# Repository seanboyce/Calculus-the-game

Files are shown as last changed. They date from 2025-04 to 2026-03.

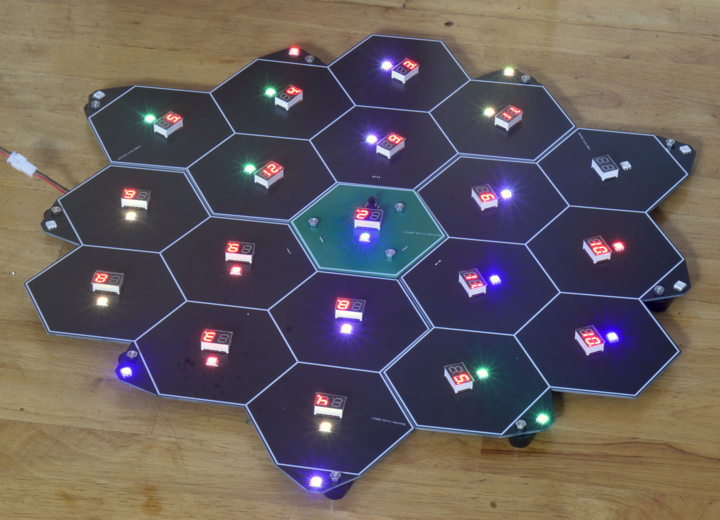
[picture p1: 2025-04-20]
calculus_full/fullboard_power.JPG

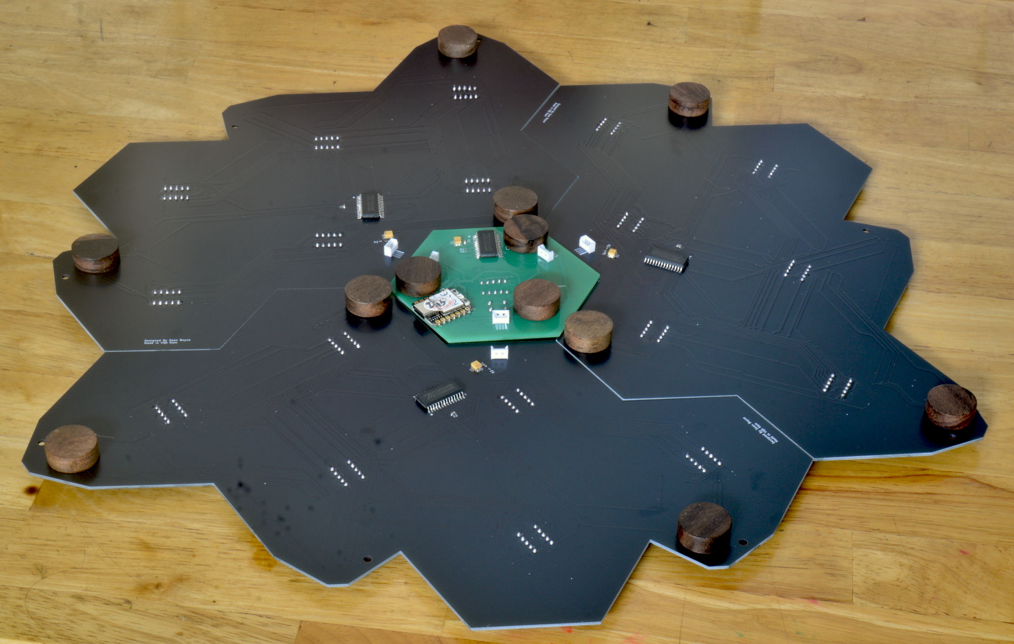
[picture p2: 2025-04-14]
calculus_full/verso.JPG

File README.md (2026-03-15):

# Introduction
An electronic strategy board game about mining an asteroid and barter. It is also fully compatible with Settlers of Catan. So if you already own that game, you can play it using this board if you wish (using the cards and pieces from the original). The holders of the Catan copyright also generously allow you to make one (1) handmade copy of their game for personal use. A practical thing to do is buy their game, and use the included pieces and cards (although please note the pieces will only physically fit the full-size version, see below). For more information on IP, please visit this link: https://www.catan.com/guidelines-dealing-intellectual-property-catan

Out of respect for their IP (and also for fun), my own game will be sci-fi themed and will not use or refer to their IP beyond this point. 

## Sci-Fi theme?
The name of the game is Calculus, in the sense of a "stone, or concretion of material". In this case, an asteroid in deep space! You are one of up to four corporations that are racing to exploit this valuable asteroid. The corporation that reaches a certain level of development (10 Infrastructure Points) first will own this tiny piece of the sky. This is the object of the game. Besides the four corporations, a mysterious hacker has made their home here, and is bound to interfere with your plans...

(for more information, read the short, bewildering manual)

# Status
The electronics and firmware are in a finished state. Game and reference cards exist and are usable, but the design is nothing special. The game manual is an A5 saddle-stitched booklet, available as a pre-imposed, print-ready document. If you want to help, please redesign my print materials. You are very likely better at this than I am.

There are two versions of this game, both complete:

1. The cheap version (about USD 15.00 to manufacture 1 unit in Asia) -- this version only has one PCB, although you will need 3 units to build the game. It is very cheap to manufacture, but a bit small and cramped to play. Call it a "travel version"! It is missing a little polish overall, and the firmware (while completely functional) is a little chaotic. Notably, trade ports are not electronic (I use magnetic discs), the landing zone (unproductive tile) is limited to being in the center of the board, and there's no MCU on the board itself -- it needs to be added externally and wired in to the inputs. You'll also need to hack in a button. Still, it's very cheap to make and perfectly cromulent.
2. The full-size version (about USD 37.50 to manufacture 1 unit in Asia) -- this one is *much larger* (more than double the size). It uses two PCBs: a large one (you will need 3), and a small one (you will need 1). The small PCB has space for an MCU, making the final board much more self-contained. The small board goes in the center and is also an active game tile -- the landing zone (unproductive tile) can be randomized like other tiles because of this. Trade ports are randomized and represented by RGB LEDs like resource tiles (or off for 3:1). There are also some cosmetic improvements like a proper button and nicer lines. I've also substantially cleaned up the firmware to control all those LEDs -- there are 388 (!) LEDs on the board when you count up all the RGB LEDs and two digit 8-segment displays. 

Other than noted above, both versions play the same. 

## Power
It's expected that you power the game via a USB battery bank. Like the kind you use to recharge phones. However, you can power it from any USB port or 5V source. Current consumption at 5v should be around 250mA for the cheap version, and a little higher for the full version (say 300mA).

Note that some power banks will automatically turn off if the power draw is too low. When pressing the 'next turn' button, the power draw can dip below this threshold, causing the game to turn off and lose it's state! To avoid this, some power banks have a 'low current mode' that disables this feature -- check your powerbank manual.

An alternative solution is to put a resistor across power and ground to increase the current draw. A 100 ohm resistor was sufficient in my case. This adds 50mA to the current consumption, but still keeps it low enough that my power bank will run the game for 30 hours or so per charge.

Building your own rechargeable power supply, or powering it from a phone charger instead of a battery are also reasonable solutions!

## CPU
The cheap version of the game can use more or less any RP2040 based board. The original Pi Pico works fine. The full version specifically requires the XIAO RP2040 -- it's smaller and I needed the space.

## Structural
The boards for the cheap version are intended to be attached above a small project box or similar. This serves the dual purpose of housing a microcontroller, and fixing the 3 PCBs firmly in place. The larger board has all those electronics integrated, and is meant to be bolted to something rigid. I use a circular bamboo serving tray, this leaves a hollow space under the board suitable for storing pieces, the power supply, and the manual.

You can also just add rubber feet to the PCB, the type that are used for furniture and attach on via M3 bolts. This will let you rest it on most flat sufaces. These should be at least 8mm high for proper clearance, I found 10mm more practical. The benefit of this approach is that you can 'stack' the 3 big PCBs, and store the game in a smaller box. On the other hand, it offers no strain relief on the cabling (which can get a bit tangled). I found that bolting it to a rigid surface was much more practical.

## Game Pieces
The cheap requires custom pieces -- hex spacers, bolts, and nuts colored with a permanent marker work fine. The full size board can be played with pieces from a Catan set, or you can make your own.

I like the weight of metal game pieces -- so I dyed 25mm brass hex spacers as the 'tunnels', dyed M6 nuts as the 'mines', and add a ~13mm dyed M6 bolt to them to upgrade them to 'drills'.

To dye these metal pieces, colored permanent marker worked really well.

# Firmware
Besides the assembled PCBs, you will need to load firmware to the main microcontroller (an RP2040). This is pretty easy and can be done over USB. The firmware is heavily commented -- this is so you can make 'house' modifications to the game mechanics, to change the rules if you want. You could even design a completely new game!

# Notes on Assembly
Assembling the PCBs will require that you are comfortable with surface-mount soldering. It's not nearly as hard as it looks. You'll need solder paste and a hot air rework station though. If you don't have these, check if there's a hackerspace near you. They probably will! The default designs use 0402 (1005 metric) components. If you want something easier to solder, look for the 0603 version of the kicad and production files in the fullsize board directory. 

# Having Trouble? Something Confusing?
Raise an issue here on Github. I check in from time to time and will likely respond.

# Image of Completed Board (full version)
Photo of the completed full version of the game

# Image of Completed Board (cheap version)
Photo of the completed small version of the game

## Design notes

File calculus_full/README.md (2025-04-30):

## Resistor sizes

I've supplied two versions of the kicad and production files. The default version uses 0402 (1005 metric) components. Many people would find these hard to hand solder -- they are about the size of two grains of salt. If you want something easier to solder, check out the 0603 version -- there's a zip file with the KiCAD and production files. Strictly speaking, it's not tested (I made the 0402 version). However, the only thing I did is change the resistor footprints, so it should be fine. 

## Note the production files are in metric units

If you need to switch it to some other system, you'll need to open the KiCAD files and generate your own production files (it's very easy)

Also note these boards have a little note in silkscreen on the back with my name and where they were designed. It's meant to be a kind note that I cared to design these for you, and I hope you enjoy them.

You may remove it if you wish. Just open up the PCB in KiCAD, select the text, and press delete. Then re-export the production files.

## KiCAD files

There are some custom footprints I think? Not sure how that gets handled. Let me know if anything outright breaks.

The routing is still pretty YOLO in this version (although less bad than the cheap version), feel free to clean it up. I tried to mostly keep traces off the top of the board so it looks clean.

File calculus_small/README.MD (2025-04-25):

# Pieces
For this game size, brass hex spacers, bolts, and nuts work really well.

- Hex spacers are 'tunnels'
- Nuts are 'mines'
- Nuts with a bolt slightly screwed in are 'drills'

If you color them with permanent marker, they look quite nice.

# Routing
Yeah, the routing on this board is very YOLO. Feel free to make improvements. I have only a few hours of free time per week so optimized for getting the thing done.

# Notes
The production files are in metric units.

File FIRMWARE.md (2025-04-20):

## Make sure to use the right version of the firmware for your game.

Unlike some of my other projects, this is purely written in micropython rather than AVR assembly. I wanted it to be more accessible to beginners, and the extra power use by the RP2040 is pretty irrelevant in the context of all the LEDs.

The firmware uses the tm1640 driver from here: https://github.com/mcauser/micropython-tm1640. The licence for that code is different from the rest of this project, and defined in that file.

To learn how the firmware works, your best bet is to read the source code in main.py for the full version of the game. It's heavily commented.

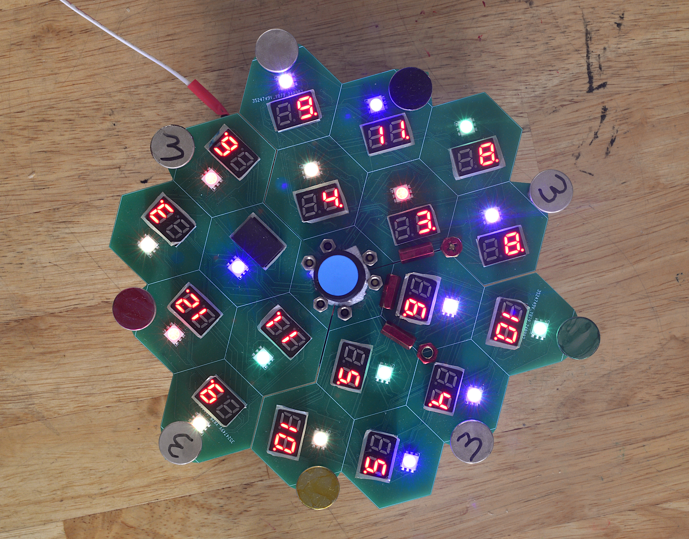
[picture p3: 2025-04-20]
calculus_small/calculus_small.JPG

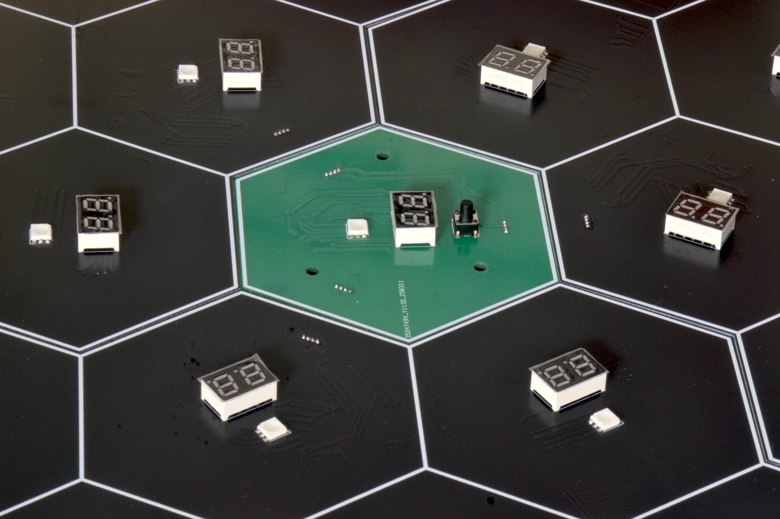
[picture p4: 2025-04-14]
calculus_full/unpowered_close.JPG

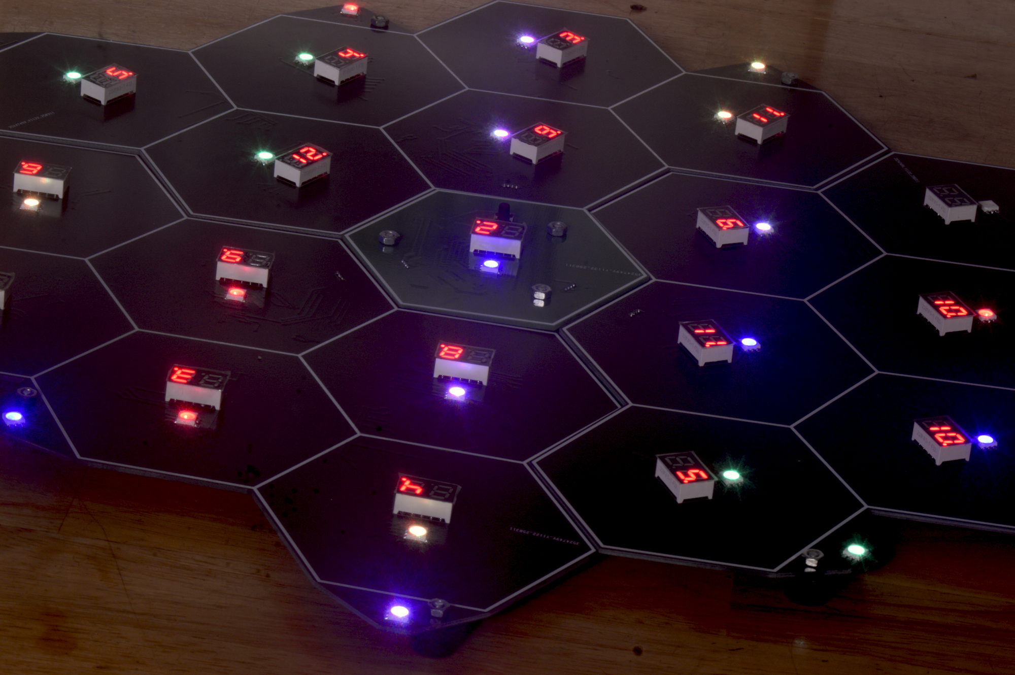
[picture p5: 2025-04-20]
calculus_full/closeup_power.JPG

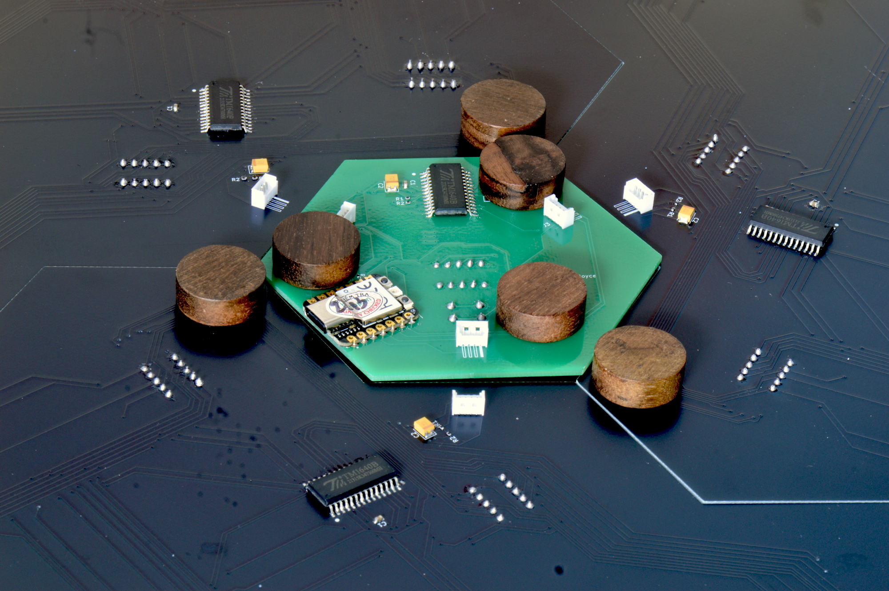
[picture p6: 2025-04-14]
calculus_full/verso_close.JPG

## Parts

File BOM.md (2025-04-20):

All parts surface-mount unless otherwise noted. Let me know if I've missed something. Black PCBs look pretty cool with this design.

## for 3 Main segments
- 3x TM1640 LED drive control IC
- 18x two-digit LED display, common ground (I used 2821AS, these are through-hole parts)
- 27x 5050 RGB LED
- 3x 1.25mm ZH female connector (these are through-hole parts)
- 3x 1411 Tantalum capacitor 100uf 6.3V
- 3x 0603 0.1uF ceramic capacitor 50V
- 6x 0402 10k ohm resistor
- 3x PBC subunit

## For center tile
- 1x TM1640 LED drive control IC
- 3x 0402 10k ohm resistor
- 1x 1411 Tantalum capacitor 100uf 6.3V
- 1x 0603 0.1uF ceramic capacitor 50V
- 1x 5050 RGB LED
- 1x generic pushbutton. Check the board for dimensions, it's one of the super common types (this is a through-hole part)
- 1x two-digit LED display, common ground (I used 2821AS, these are through-hole parts)
- 1x XIAO RP2040 module (we're using it as a surface mount part!)
- 3x 1.25mm ZH female connector (these are through-hole parts)

## General
- 3x 1.25mm male-male connector (cable). Mind the pinout, some cables reverse pin order.
- 1x USB external battery for phone (to power the game)
- 1x male USB cable (for power). Probably you want one end USB, then solder the power lines directly to the center tile. I've left yo usome pads for this, but anywhere 5V/GND goes is fine.
- 15x 3mm wide bolt+nut (length depends on the rubber feet you choose)
- 15x rubber foot. Minimum length 8mm. Recommend 10mm. You can also bolt the boards to a surface instead of using feet.

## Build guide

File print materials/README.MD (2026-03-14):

# Print Materials
These are the (optional) print materials for Calculus. Each indicates how many copies of the file you'll need to print to have enough pieces.

## Manual

The manual is a bit of a special case. There's a .odt file if you want to edit it, but I've also made an attempt to lay it out into A5 pages. This lets you print it as a saddle-stiched A5 booklet. The "imposed" version is ready-to-print (duplex on long edge). The other version assumes you'll handle the page imposing yourself.

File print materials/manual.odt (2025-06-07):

Prelude

The year is unknown.

Long ago, the Earth could no longer sustain our hunger. We fled like locusts to the stars. But they were strange, and far. They did not want us, and we could not reach them.

There were nearer worlds. Dusty and without breathable atmospheres, space was safer. There was always energy available from sunlight – as long as you avoided gravity wells, the only resources of consequence were mass and time.

The asteroid belt had plenty of metals, and very little gravity. We learned long ago that economic competition was the most efficient way to deplete resources. We parceled out each to four corporations – immortal and amoral -- who would compete to devour them fastest, and thereby claim ownership.

You direct one of these. It is vast, and cold, and empty. A space devoid of stars.

Calculus: The Game

Calculus is a game of resource management and barter for 3-4 players. The word ‘calculus’ means “a stone, or concretion of material”, in this case an asteroid in deep space. The synonymity with the maths subject is not accidental either!

Before you begin, you should make sure you possess the following components:

1x game board

1x USB power bank

95x resource cards – 19 each of Iron, Titanium, Gold, Uranium and Ice

1x hacker token

4x game reference cards

16x drill pieces (four of each color)

20x mine pieces (five of each color)

25x black market cards namely:

14x Cyborg Mercenary

2x Alien Artifact

2x Space Pirates

2x Tunnel Borer

1x Fission Reactor

1x Research Lab

1x Silicon Foundry

1x Biodome

1x Data Center

Starting the Game

No dice are required to play Calculus, it is handled electronically. The board will set itself up automatically upon receiving power. Do not disconnect power while playing the game – it will not save your game state.

Objective

The objective of the game is to be the first player to accumulate 10 Infrastructure Points (IP). If during your turn, you have 10 IP, you win the game. You may only win the game on your turn!

There are 5 sources of IP:

Mines | 1 IP
Drills | 2 IP
Longest Tunnel (at least 5) | 2 IP
Biggest Army (at least 3) | 2 IP
Black Market cards, namely: Fission Reactor Silicon Foundry Research Lab Biodome Data Center | 1 IP each

Hint: It is generally practical to use a game piece to track which player currently has the largest army and longest tunnel. If you don’t 3D print one, you could design a card, or just use two different coins.

Building

Building facilities, armies, and tunnels costs resources. These are Iron (red), Titanium (blue), Gold (gold), Uranium (green), and Ice (white). There is a summary of what each costs on the game reference cards and below:

Mines | 1 Iron, 1 Uranium, 1 Gold, 1 Ice
Drills | 2 Gold, 3 Titanium
Tunnel | 1 Iron, 1 Uranium
Black Market cards | 1 Gold, 1 Ice, 1 Titanium

Mines and drills (facilities) can only be built on corners of the hex tiles, and must be connected to a tunnel. Facilities must be a minimum of two edges apart (e.g. not on adjacent corners of a hex tile).

Drills must always replace existing mines when built. Think of them as an upgrade.

Tunnels exist along the edges of the hex tiles, cannot intersect or overlap each other, and must be connected to your existing tunnel network. If your tunnel network is interrupted by another player’s facility, the tunnels past that facility no longer count as part of your network.

Gaining Resources

When any player starts their turn by pressing the button in the middle of the board, the game will electronically roll two dice, and one of two things will happen:

1. The hex tiles that produce resources will flash. Each player with a facility touching those tiles will gain one resource of the type indicated by the colored LED. If you have a mine, you gain one resource card of that type. If you have a drill, you get two. If you have more than one facility touching the flashing tiles, you gain resources from each.

2. All tiles flash! You have been contacted by the Hacker. You may move them to any hex tile – that tile no longer produces resources while the Hacker remains. You may also take up to 1 resource card at random from one player, if they have a facility touching that tile. Finally, any player with more than 7 resource cards in their hand must choose and discard half (rounded down).

You should keep your resource cards hidden from other players.

Probability of Different Tiles Producing Resources

The numerical LEDs on each tile tell you what number needs to be rolled (on two dice) for that hex tile to produce resources. Numbers closer to 7 are more likely, like with actual dice. In other words, 8 and 6 are the most productive hex tiles. 2 and 12 are the least productive.

Each possible roll has two tiles except 2 and 12 which occur once (these rarely produce resources), and 7 which summons the Hacker instead of producing resources.

You may notice that one tile has no number. This is the “Landing Zone”. The Landing Zone produces no resources, and the Hacker starts the game there.

Just in case it’s not clear, this is the resource that each tile produces, according to the LED color:

Red tiles produce Iron

Blue tiles produce Titanium

Yellow tiles produce Gold

Green tiles produce Uranium

Trading Resources

You may trade resource cards with any player, but all trades must involve the player whose turn it currently is.

You may also trade resources with the market during your turn. The market hungers and will not offer you a great rate – 4 of any one type of resource for one resource of your choice. There are some things you can do to get a better rate:

1. If you own a facility touching one of the unlit LEDs on the outside of the board (not on a hex tile), you may trade three resources of the same type for one resource of your choice. These are the general trade ports.

2. If you own a facility touching one of the lit LEDs on the outside of the board (not on a hex tile), these are the specialized trade ports. You may trade two resources of the same color as the LED for one resource of any type.

In both of these cases, the facility must be build on a hex corner directly connected to the trade port, and not on some further part of the hex tile.

Generosity is a Crime

Your shareholders do not tolerate generosity, it is punishable by death. You may not give resource cards to another player for free. This includes combining a series of trades that results in one player receiving free resources from another at no net cost.

For example, you cannot trade another player two Iron for three Iron. Neither can you trade an Iron for a Uranium and Ice, then immediately trade one Ice for one Iron – one player netting a free Uranium at no cost. There must always be a cost, the market demands it.

Turn Actions

Calculus is a turn-based game. Each turn has two phases: Resource Extraction and Action.

Resource Extraction Phase

Players start their turn by pressing the button in the center of the board – this rolls the electronic dice, starting the Resource Extraction phase.

The game will automatically determine which tiles produce resources and flash the numbers on those tiles. Players take one resource of that tile’s type for every mine touching it, and two for every drill. If all tiles blink, the Hacker has contacted you, in this case no resources are produced.

Any tile with the Hacker present produces no resources. The landing zone also produces no resources. To indicate this, it is convenient to use a small piece of black plastic to cover the numeric LED display.

If there are not enough resource cards left for a player to receive them, no player receives those resources on this roll. For example if two players need to receive Titanium, but there’s only one card left, neither player receives any Titanium. If only one player needed to receive two Titanium, then they could draw the remaining card.

Spent and discarded resources are returned to the pile.

Action Phase

If it is your turn, you may now trade with any other player (or the market). You may buy Black Market cards, build tunnels, mines, and drills. You may do these as many times as you want, provided you have the resources. (Some players like to put a time limit on turns, but that’s up to you.)

You may also play one Black Market card, unless you drew it this turn. One exception: you may play any number of the following cards if they bring you to 10 Infrastructure Points:

Fission Reactor

Silicon Foundry

Research Lab

Biodome

Data Center

Generally it is to your advantage to conceal these cards until that happens.

If at any point during your turn, you have 10 Infrastructure Points, you win the game! If you reach 10 Infrastructure Points during another player’s turn, you do not immediately win the game. You must wait until your turn begins.

Black Market Cards

During your turn, you may buy Black Market cards with one gold, one ice, and one titanium. You should keep these cards hidden from the other players. Once deployed, Black Market cards do not return to the pile. If they run out, no more may be purchased.

Black Market cards cannot be traded, cannot be stolen by the Hacker (professional courtesy), and cannot be deployed the turn they are drawn.

The only exception are the 5 cards that give you Infrastructure Points:

Fission Reactor

Silicon Foundry

Research Lab

Biodome

Data Center

These do not need to be deployed at all. They are worth 1 Infrastructure Point each. If they would bring you to 10 Infrastructure Points during your turn, you reveal them and immediately win the game.

The other Black Market cards work as follows:

Cyborg Mercenary: Move the Hacker to a tile of your choice. This means you may steal one resource card from one player with a facility touching that tile. The Cyborg Mercenary counts towards “Largest Army”. If you have the most mercenaries (and at least 3), that’s worth two Infrastructure Points.

Moving the Hacker this way does not require that players discard resource cards if they have more than 7.

Alien Artifact: Not much is known about this thing, but it’s certainly valuable. You may deploy this card to gain any two resources (they don’t have to be the same type)

Tunnel Borer: This boring machine lets you immediately build up to two tunnels at no resource cost.

Space Pirates: Driven mad by silence and time, they will steal all resources of one type of your choice, from all players, and give them to you. For example if you name “Iron”, all players must hand you all of their iron.

The Hacker

Bound by the mandates of their unknowable gods, the Hacker will contact you to offer their services every time you roll a 7 (all the numerical displays will blink to indicate this).

First, any player with more than 7 resource cards must choose and discard half of them (rounded down). The Hacker is a heretic that hates greedy corporations.

You may then move the Hacker to a tile of your choice. That tile produces no resources until the Hacker is moved again.

The Hacker, in their generosity (a capital offense) will also let you steal one resource card at random from one player who has a facility touching the tile you just moved the Hacker to. You may only select one player to take a card from this way.

The Hacker begins the game in the Landing Zone – the tile that has no number on it.

Determining the Longest Tunnel

When determining the longest tunnel, do not count branches. Only count the longest route that you can travel without doubling back.

If someone places a facility along your tunnel, that creates a blockade! You may not pass a blockade when counting the longest tunnel.

Setting up Your First Game

Now that you know the rules, lets set up your first game.

First, choose a player and turn order any way you wish. One practical method is to press the button in the center of the board and see who gets the highest number, then proceed to the left. Resolve any ties by trying again.

Next, players place one mine each according to their turn order. Then they place one tunnel on an edge connected to that mine. Facilities must remain at least two edges apart.

Then, in reverse turn order, players place a second mine anywhere on the board (but again, at least two edges away from other facilities). Next, they place a tunnel connected to this second mine.

This means that the last player to place their first mine, is the first to place their second mine.

Finally, each player takes one resource card of each type connected to their second mine, as indicated by the colored lights on the tiles. These are your starting resources (up to 3 cards). The landing zone produces no resources.

Now, the first player’s turn begins.

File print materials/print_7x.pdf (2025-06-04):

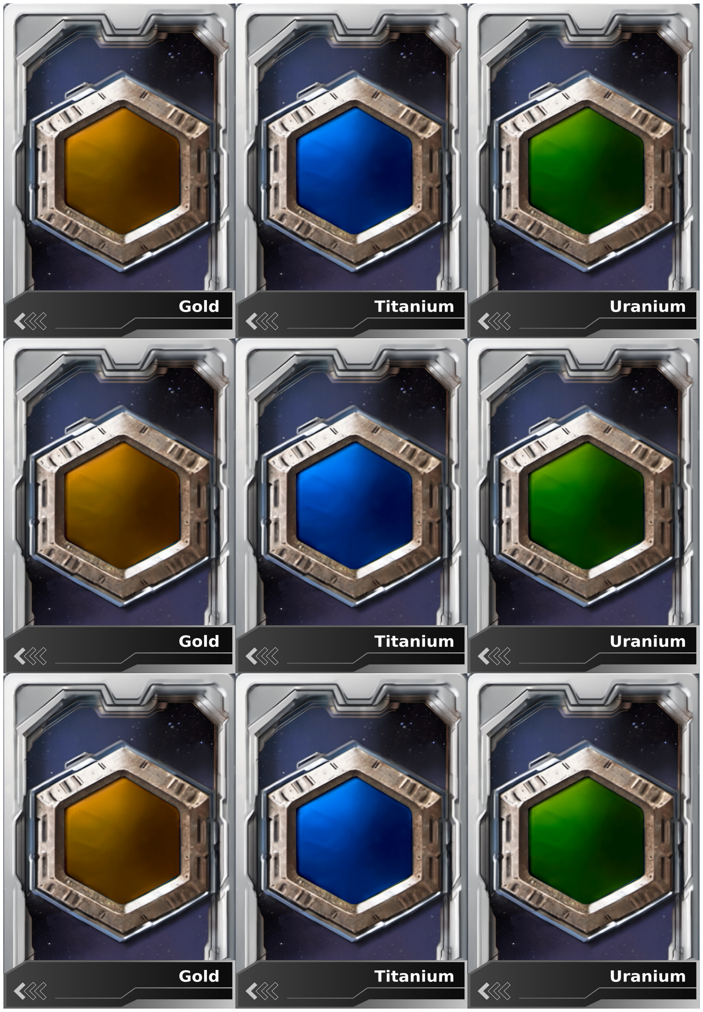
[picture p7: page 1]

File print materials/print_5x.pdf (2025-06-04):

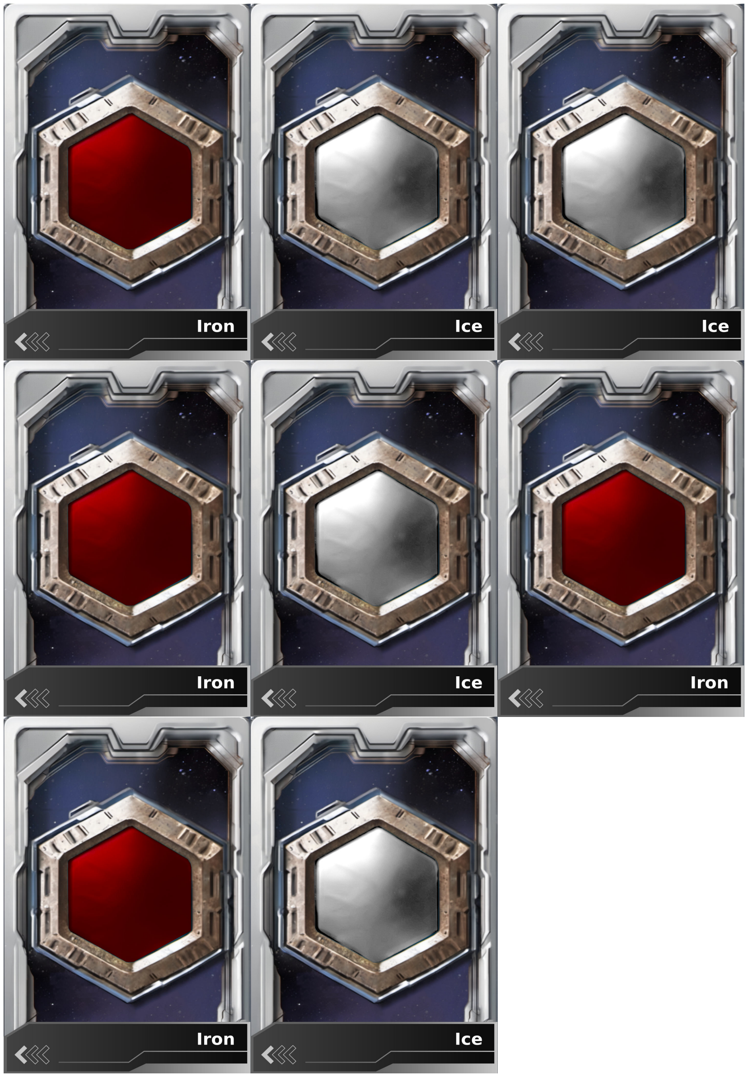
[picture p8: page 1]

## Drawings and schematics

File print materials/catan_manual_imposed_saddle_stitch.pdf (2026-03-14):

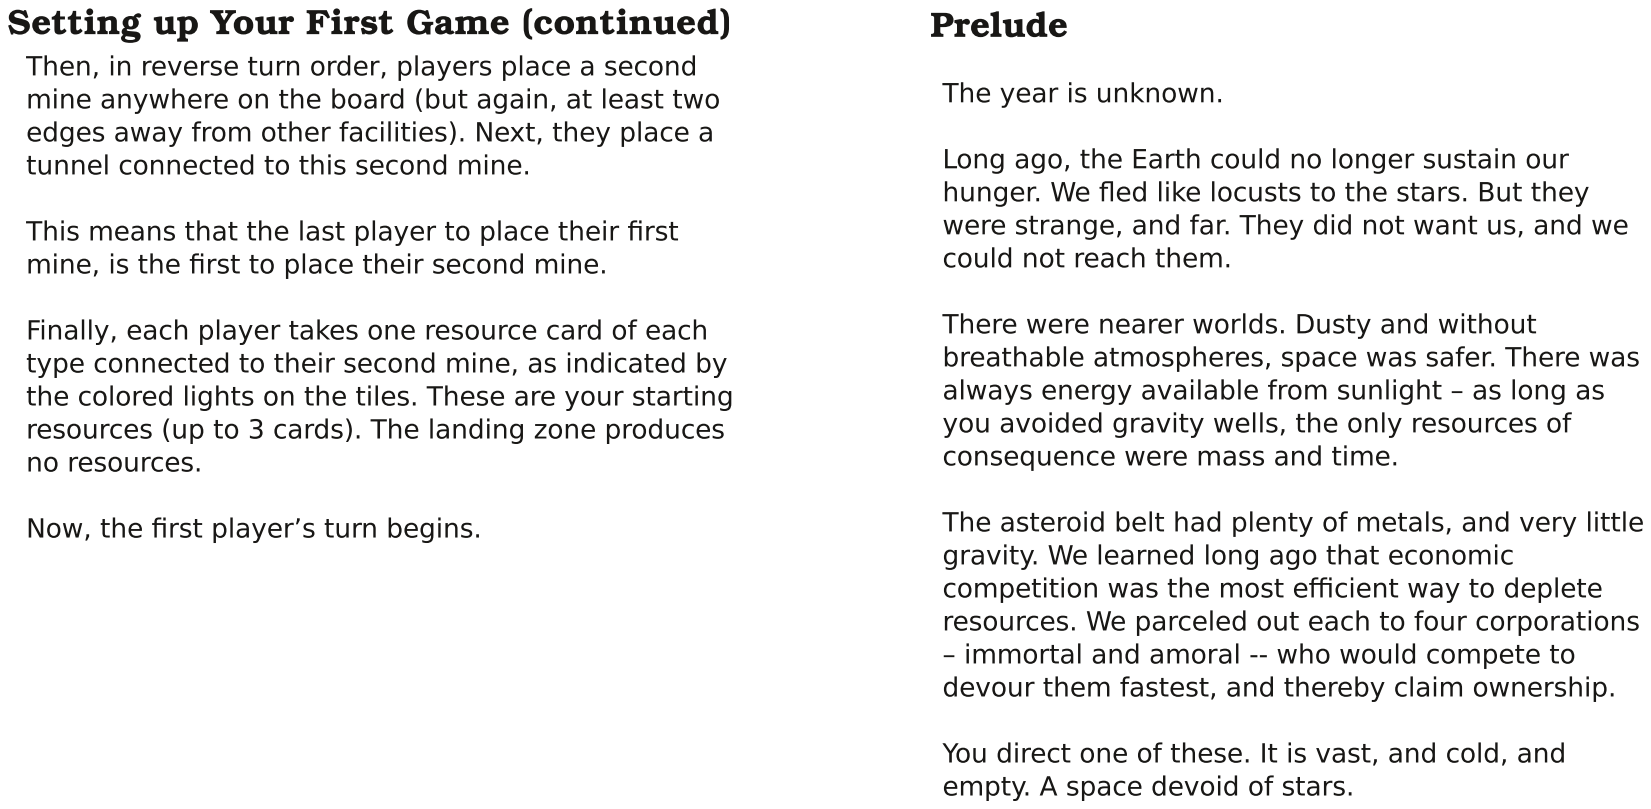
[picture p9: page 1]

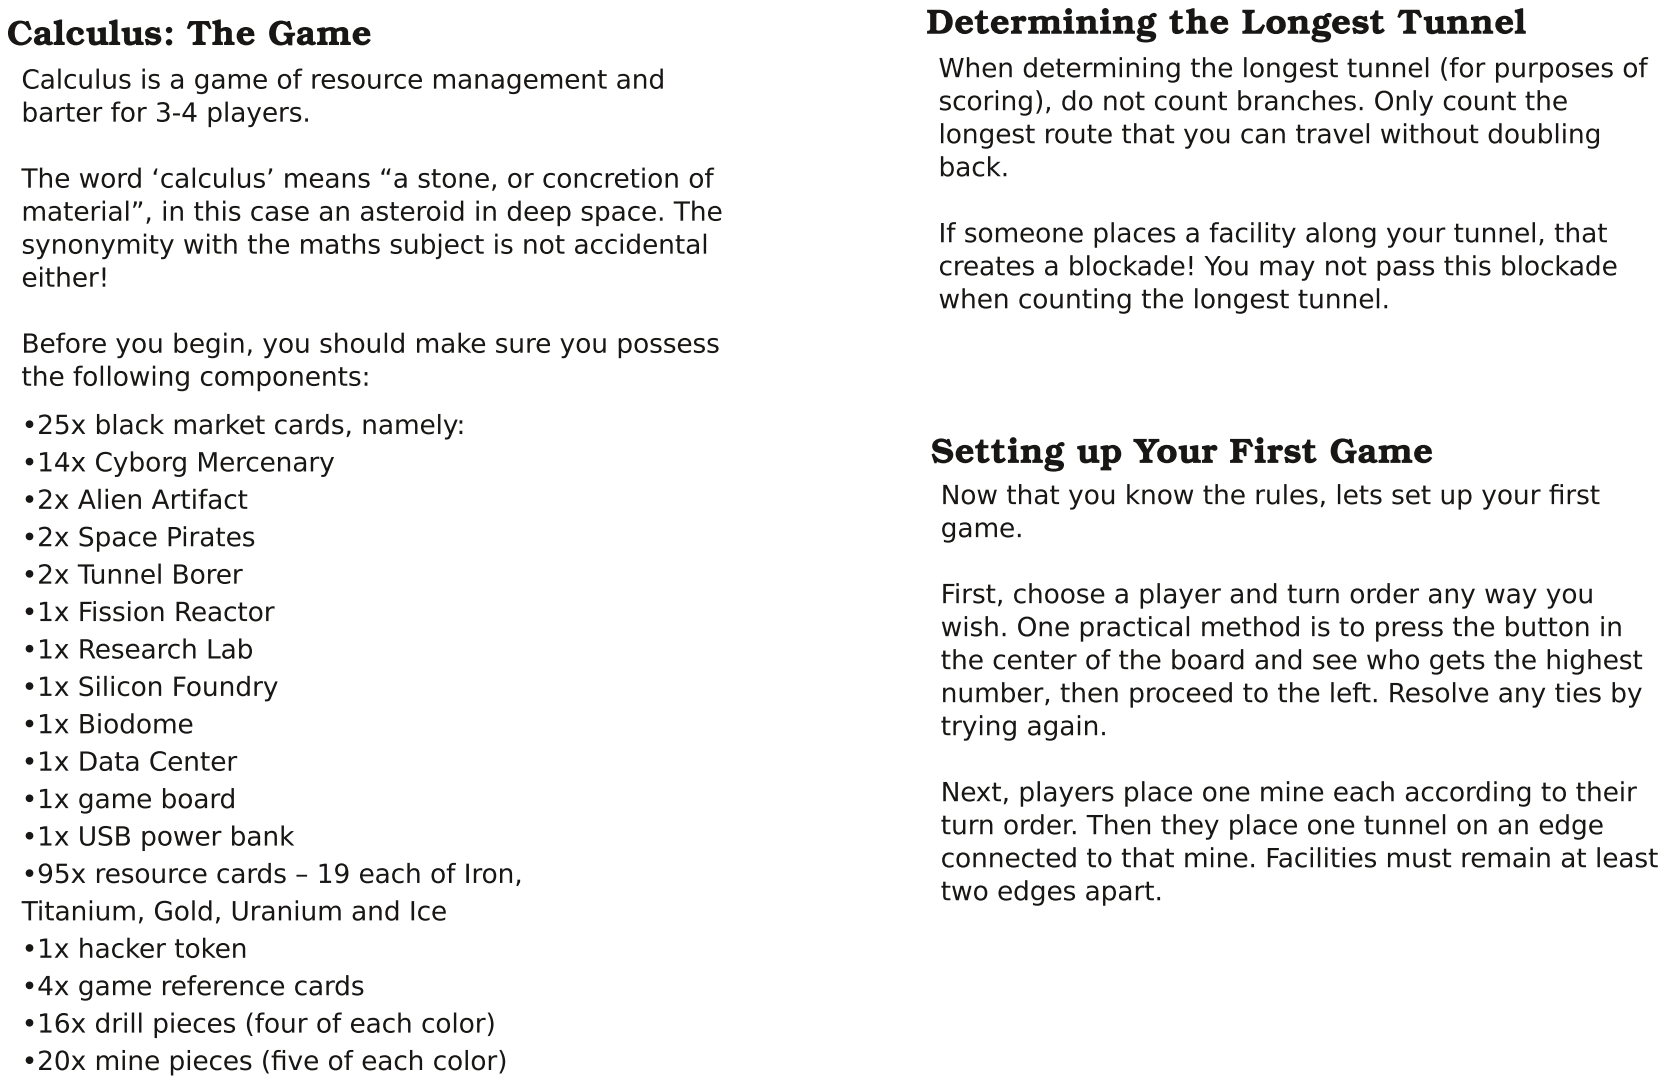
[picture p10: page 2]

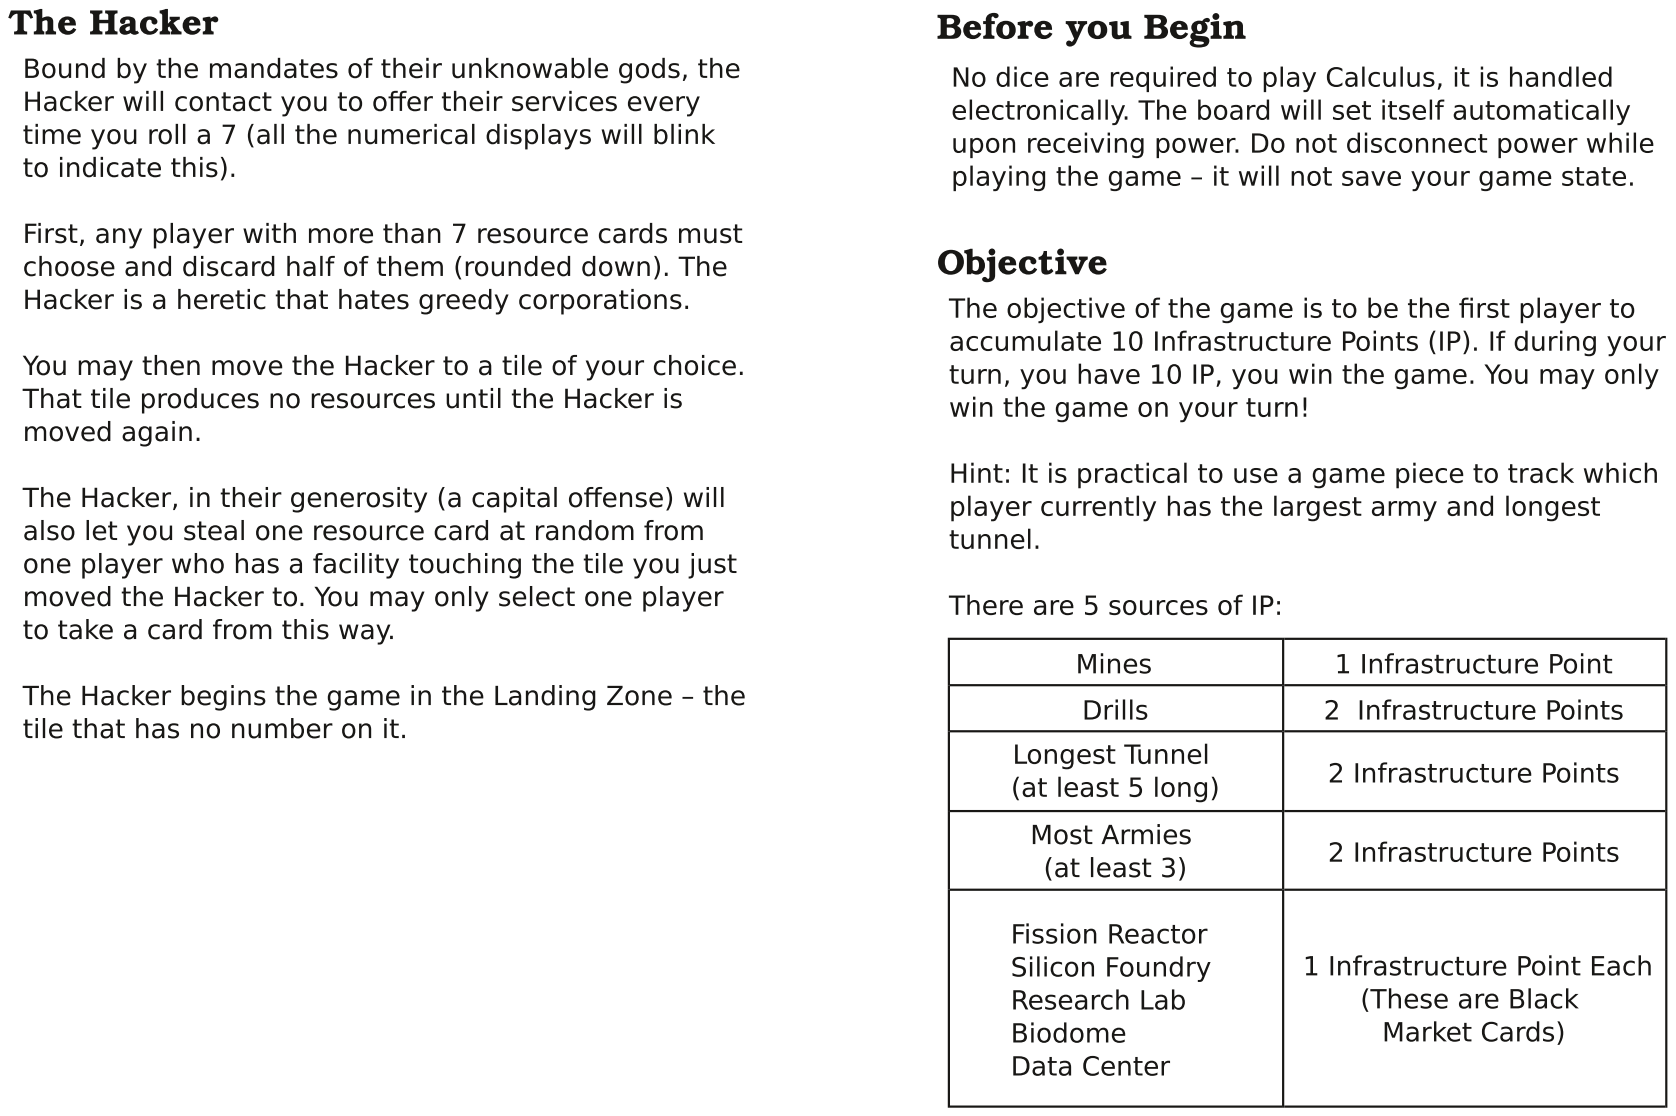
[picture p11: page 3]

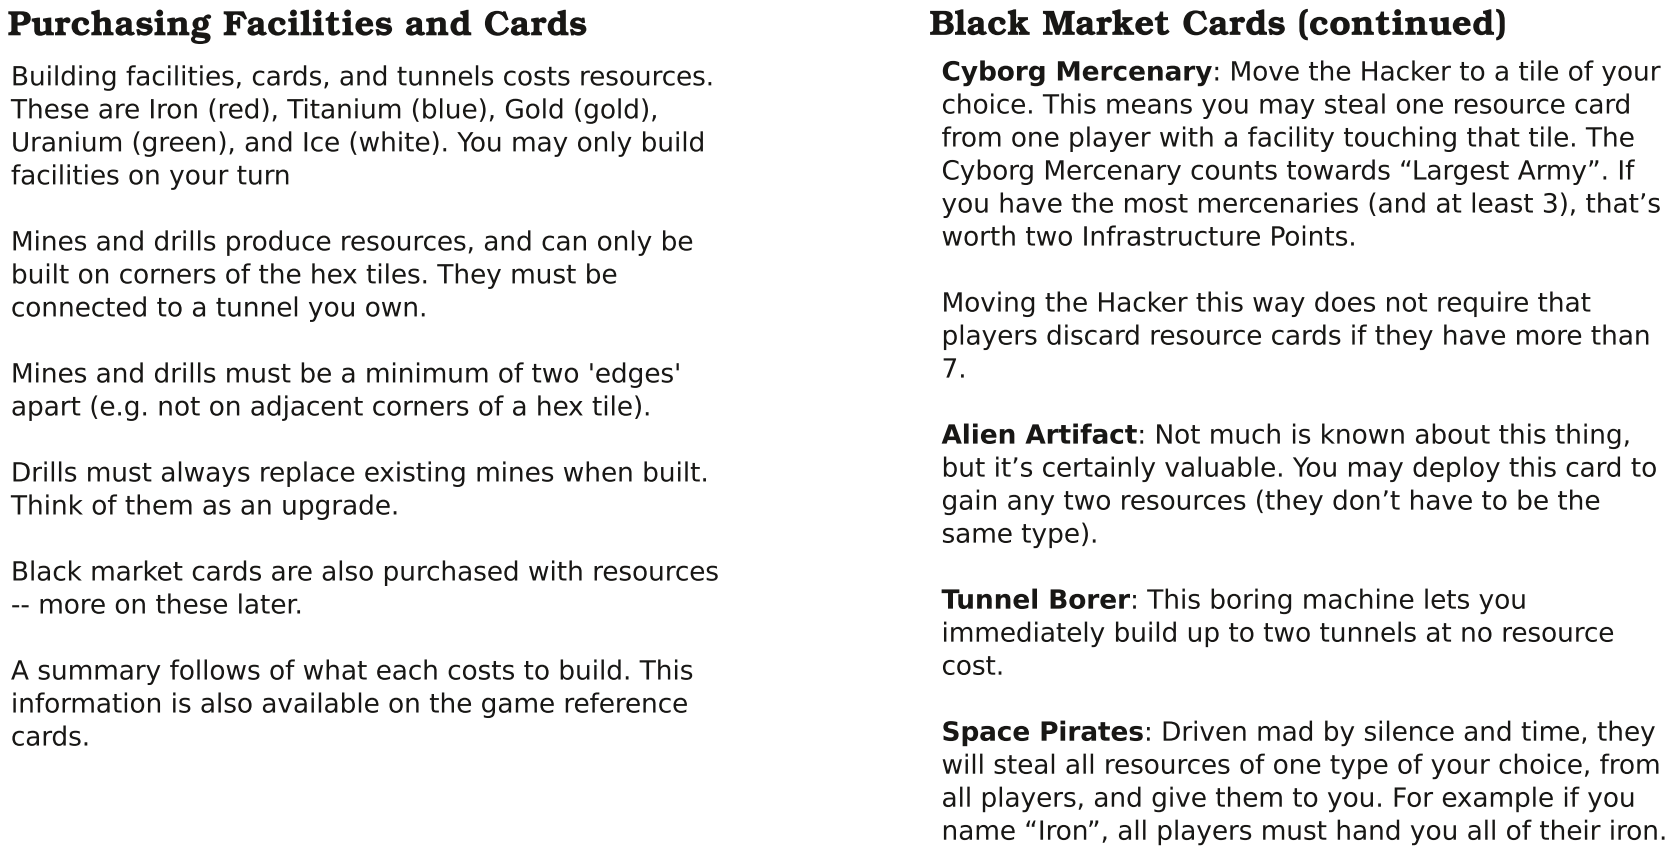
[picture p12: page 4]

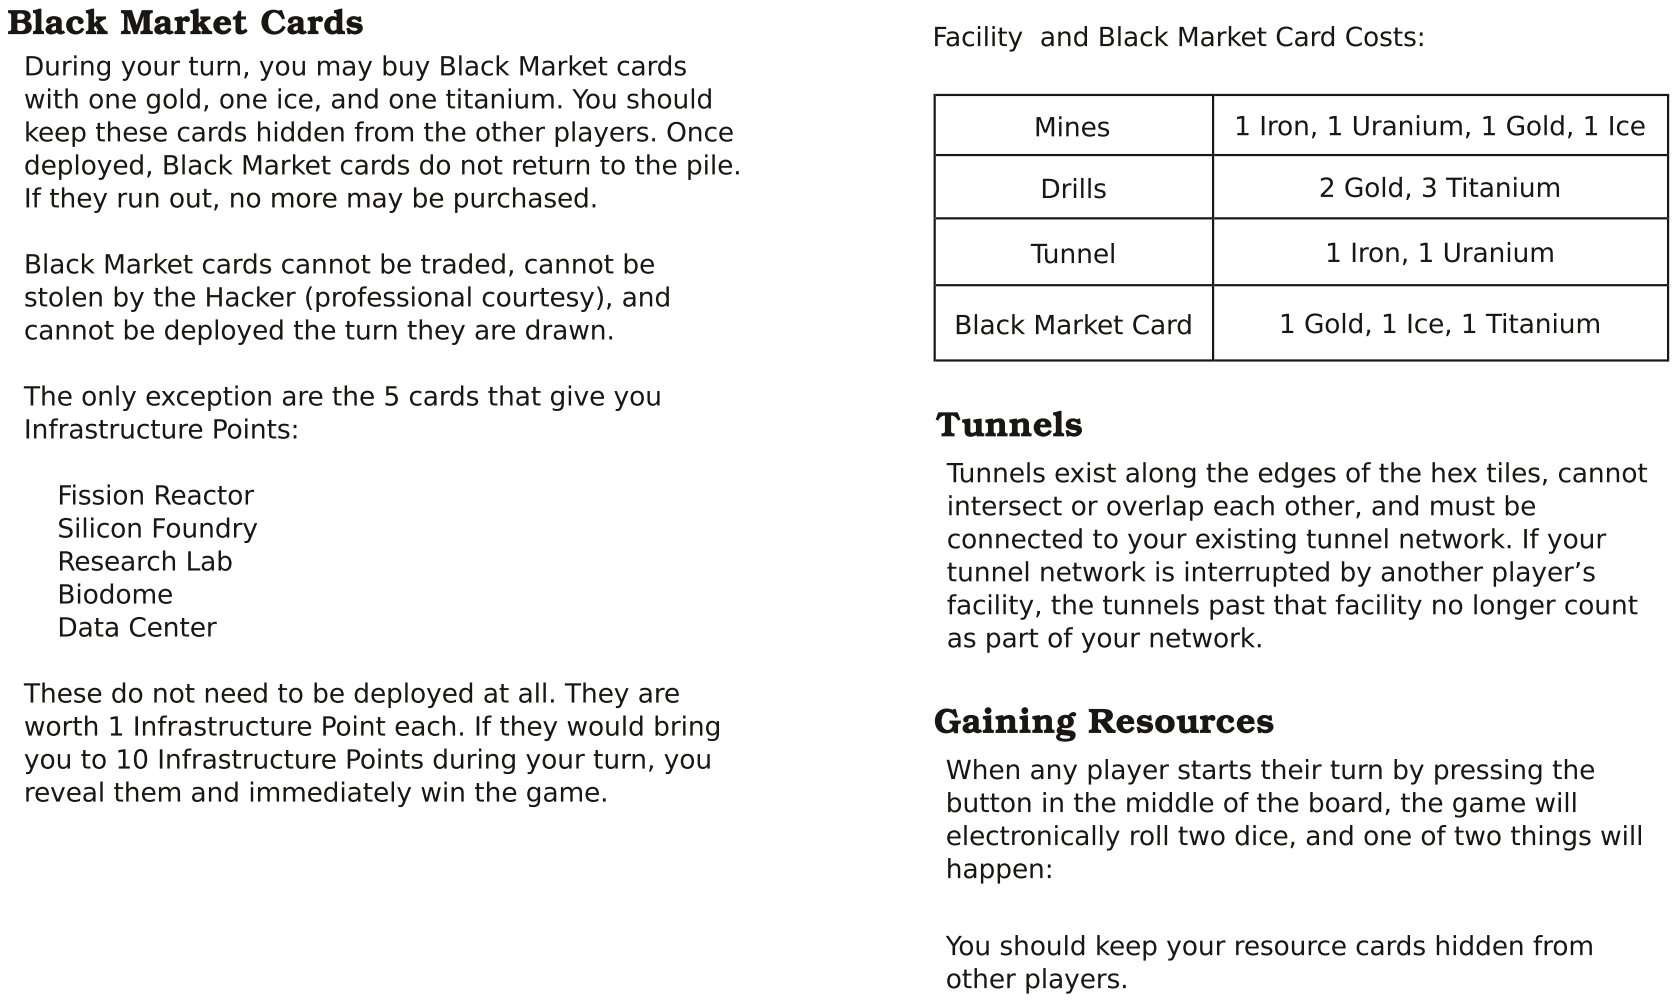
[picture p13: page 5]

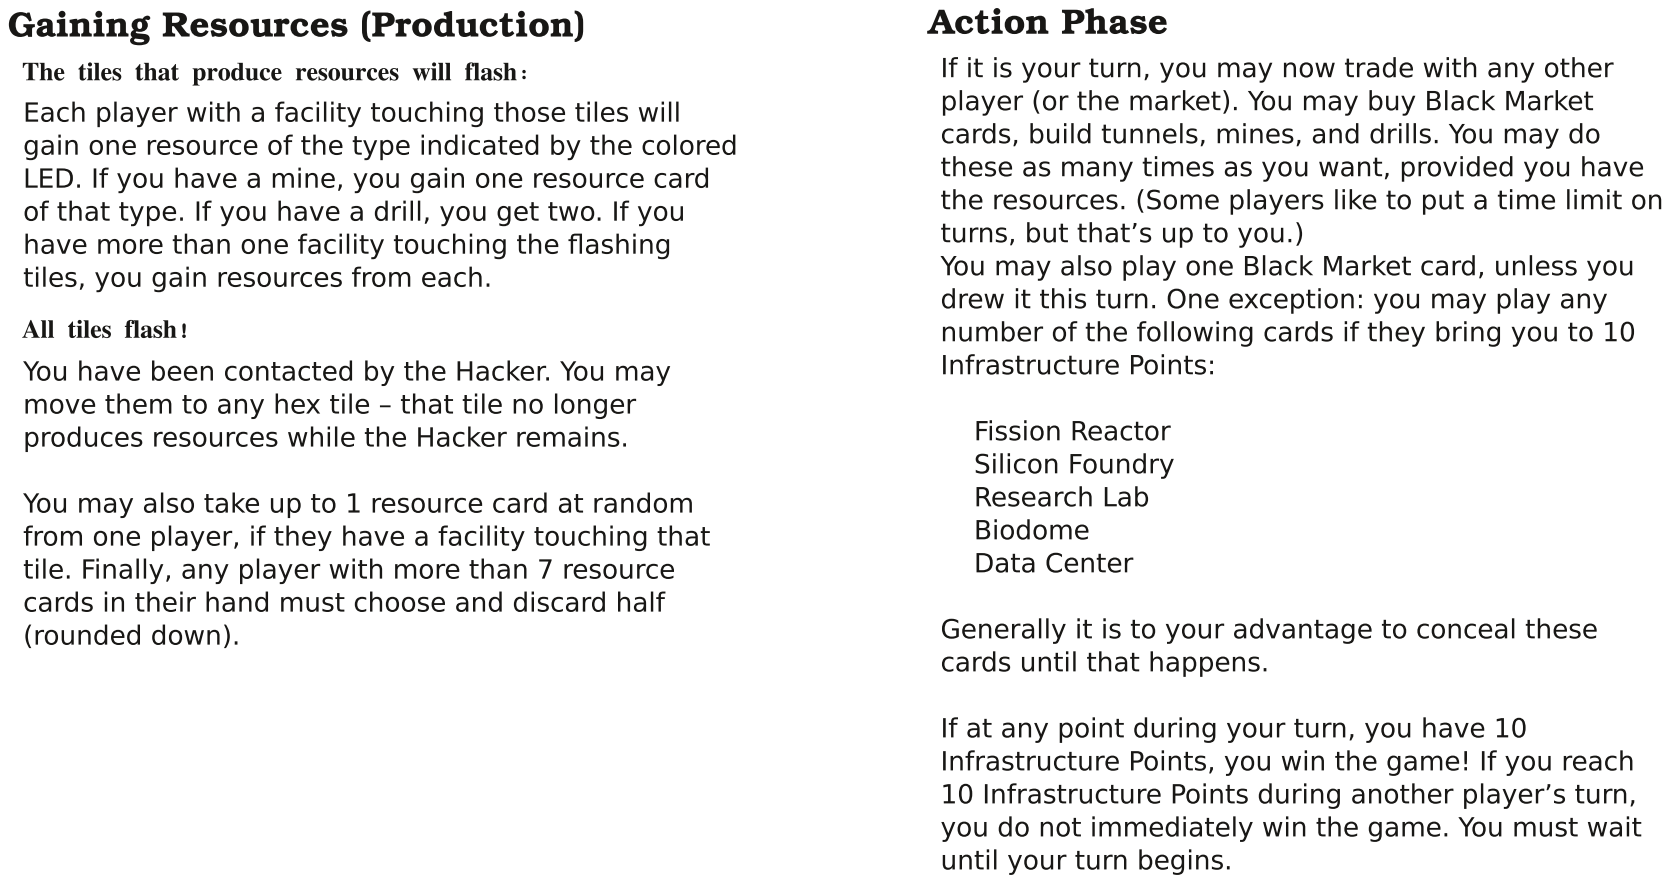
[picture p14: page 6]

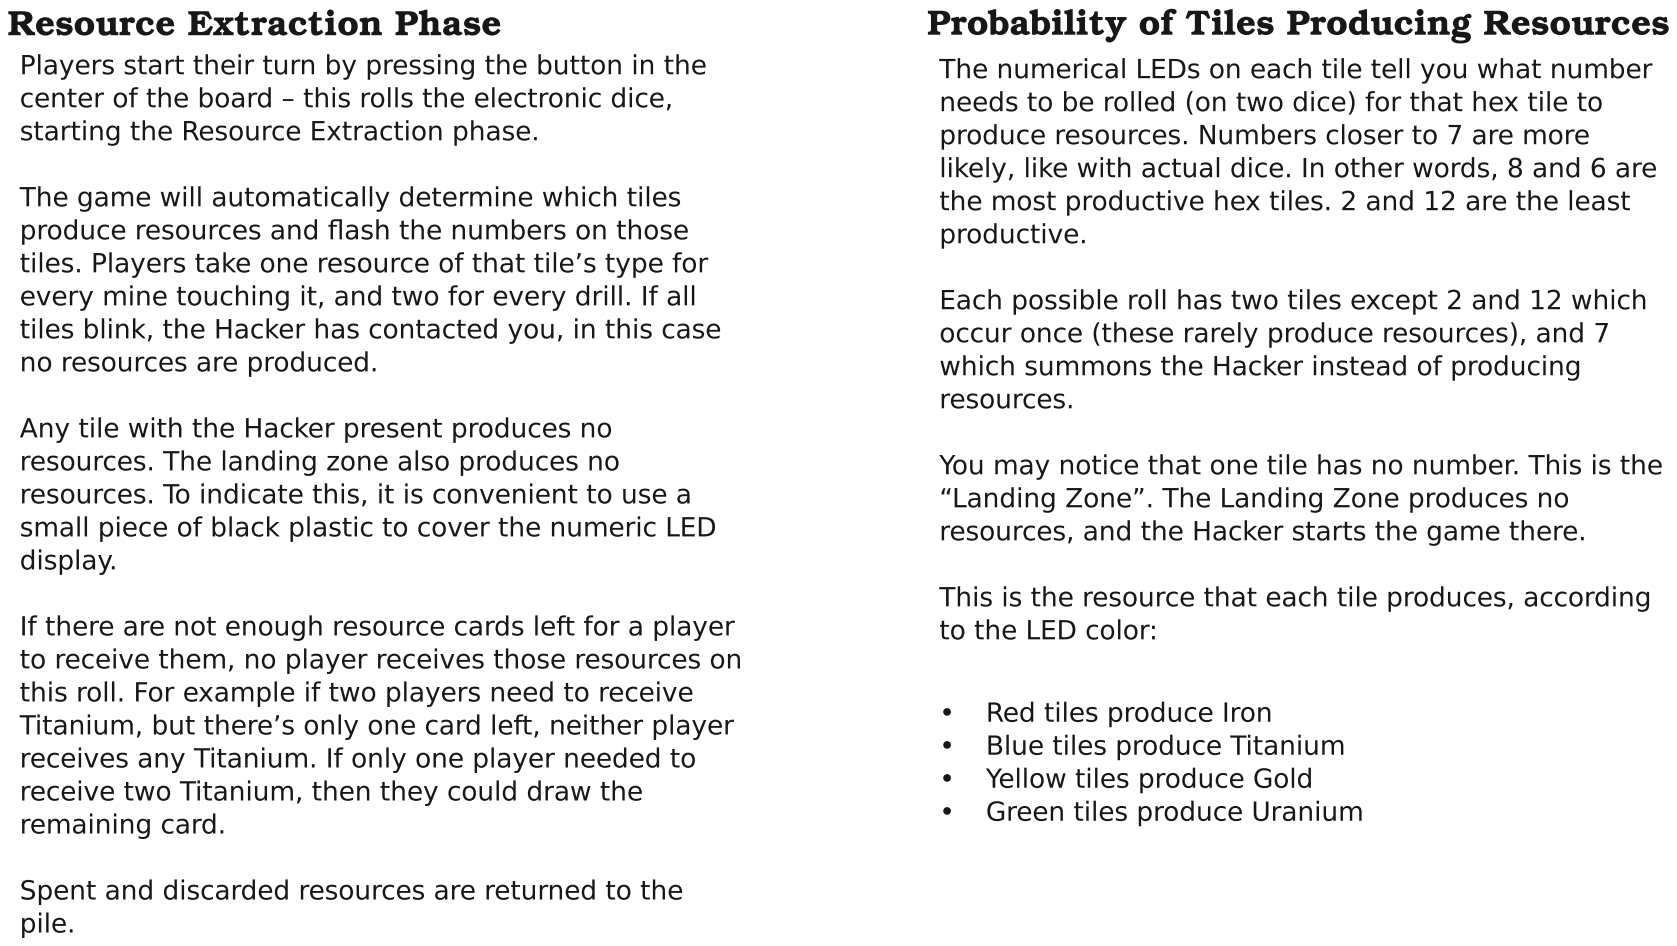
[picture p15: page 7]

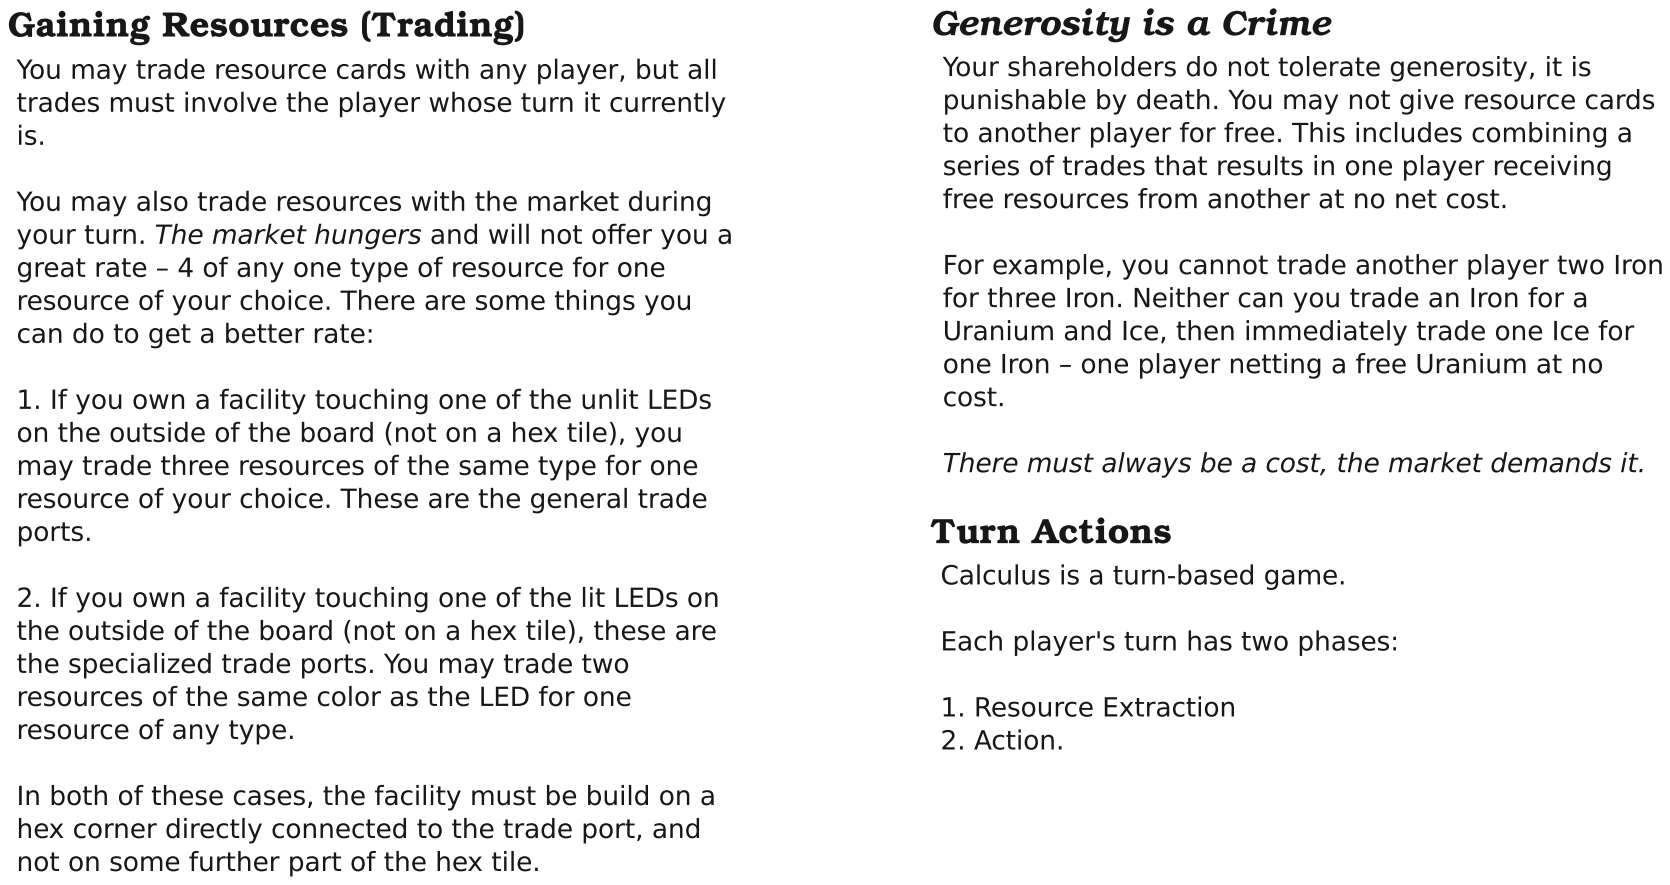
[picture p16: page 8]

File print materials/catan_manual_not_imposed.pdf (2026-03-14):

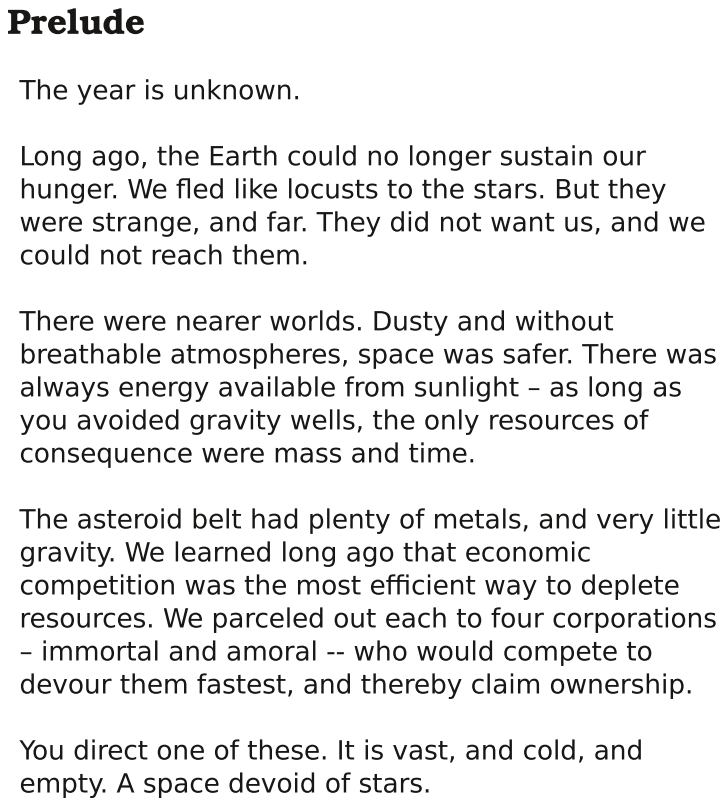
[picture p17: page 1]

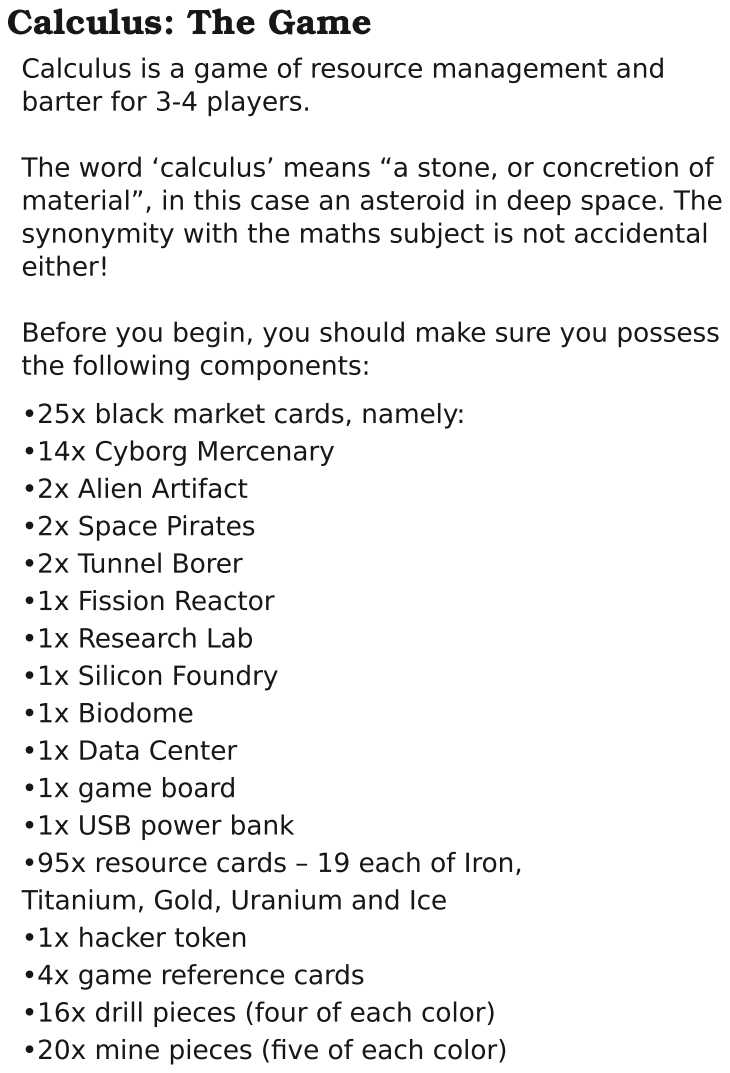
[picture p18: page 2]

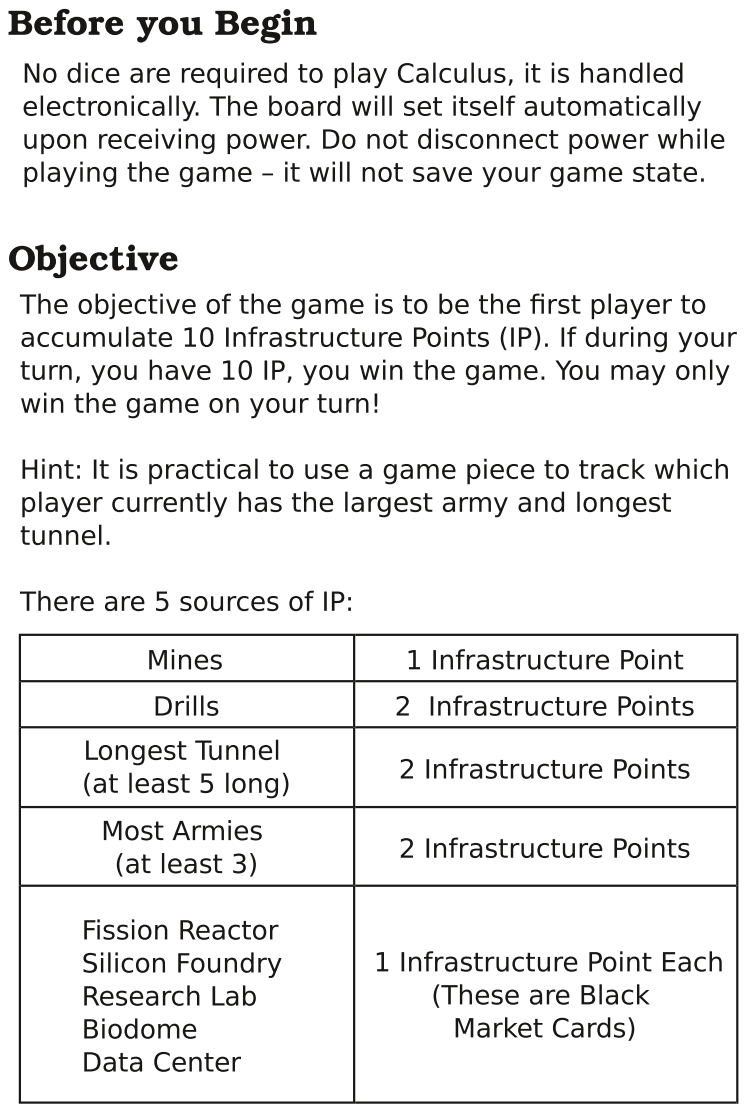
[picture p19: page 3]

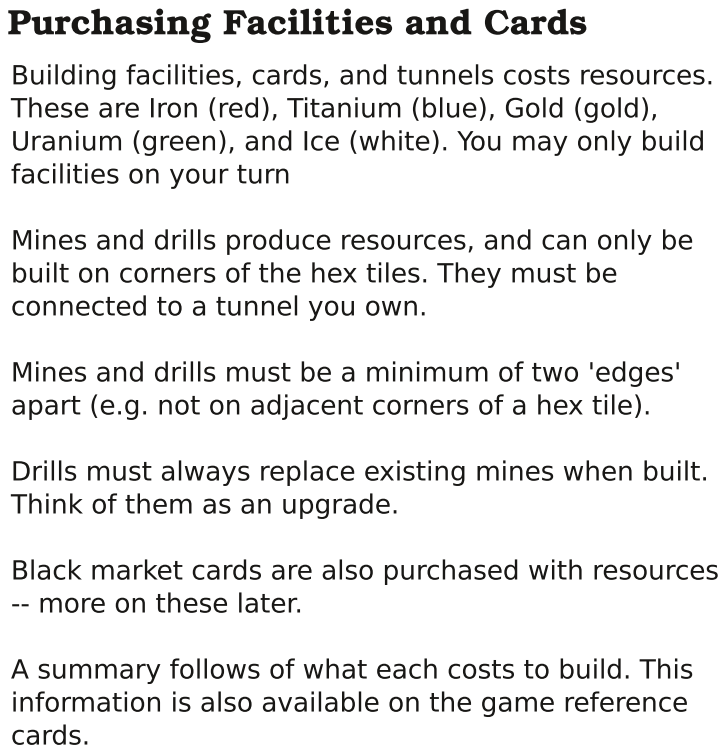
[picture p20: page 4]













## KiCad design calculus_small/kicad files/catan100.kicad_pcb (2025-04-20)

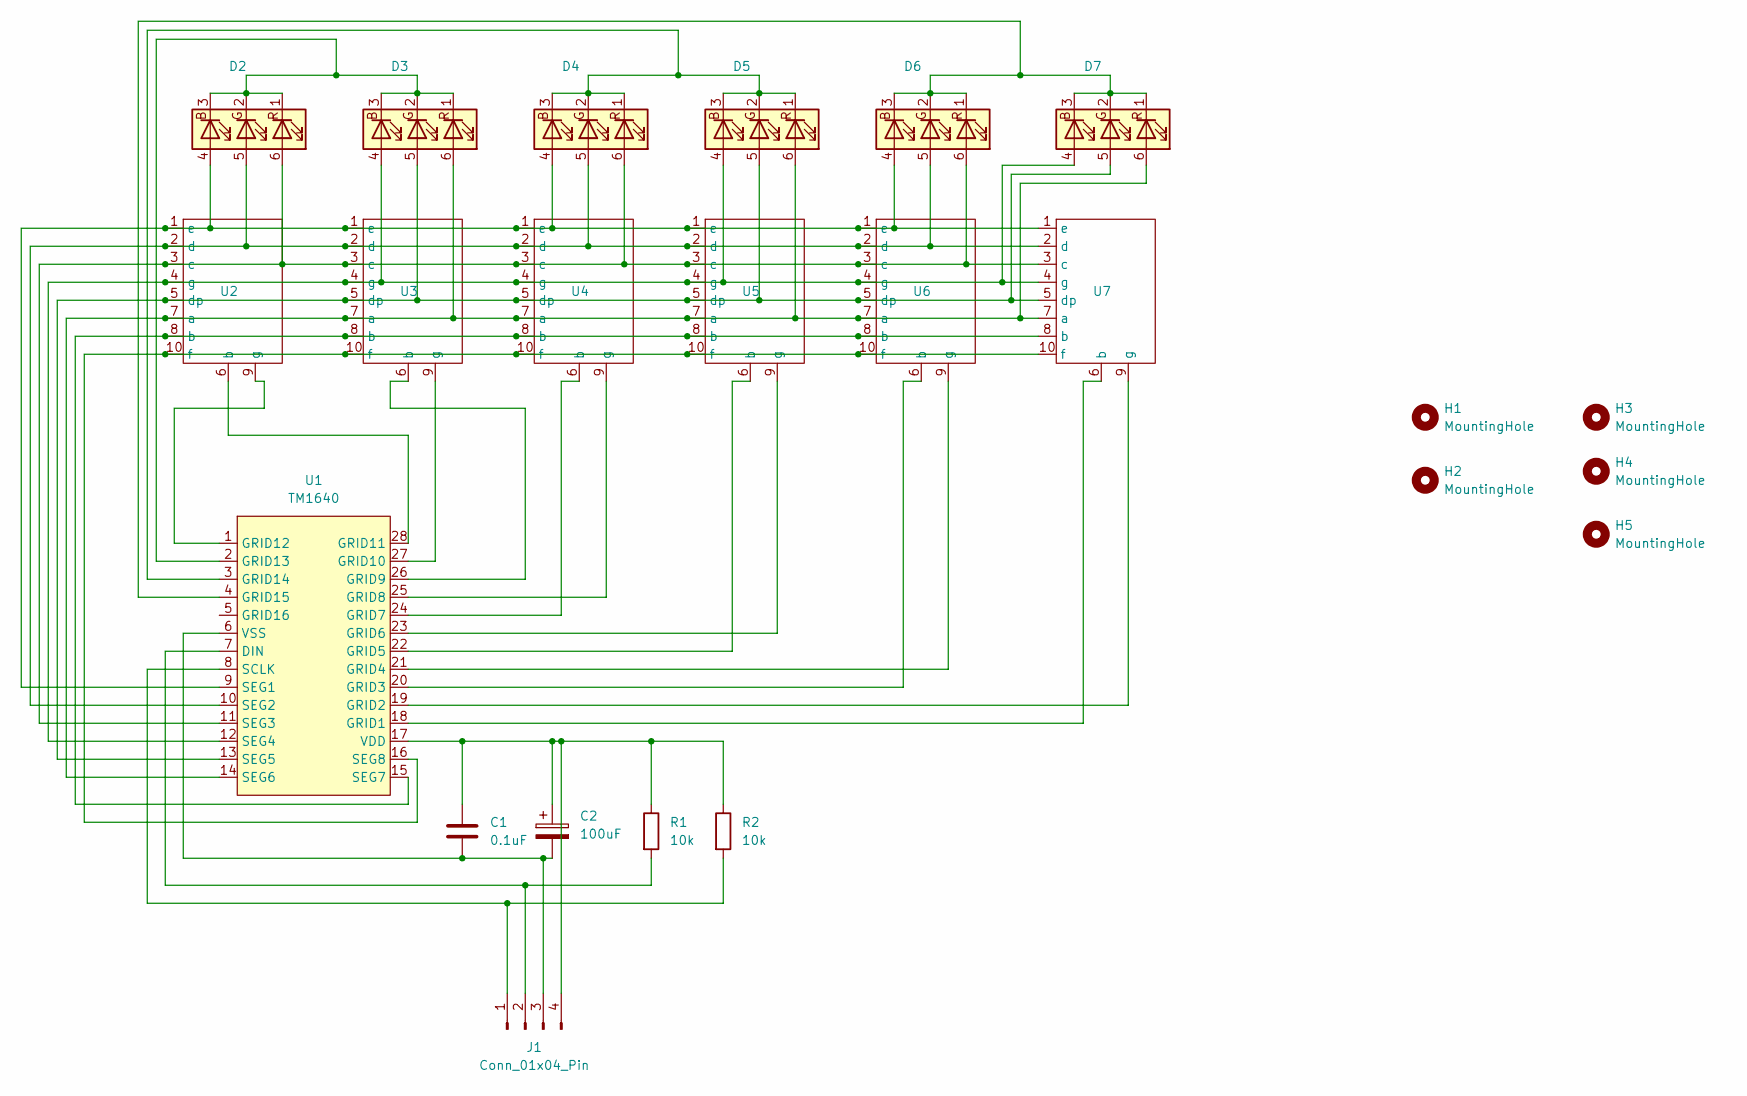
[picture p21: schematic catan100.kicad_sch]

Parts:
C1: 0.1uF; C_0603_1608Metric
C2: 100uF; CP_EIA-3528-12_Kemet-T
D1: D2; LED_RGB_5050-6
D2: D3; LED_RGB_5050-6
D3: D4; LED_RGB_5050-6
D4: D5; LED_RGB_5050-6
D5: D6; LED_RGB_5050-6
D6: D7; LED_RGB_5050-6
H1, H2, H3, H4, H5: MountingHole; MountingHole_3.2mm_M3
J1: Conn_01x04_Pin; PinHeader_1x04_P1.27mm_Horizontal
R1, R2: 10k; R_01005_0402Metric
U1: TM1640
U2, U3, U4, U5, U6, U7: 7seg2_small

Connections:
unnamed: D1.4 (BA), D3.4 (BA), D5.4 (BA), U1.9 (SEG1), U2.1 (e), U3.1 (e), U4.1 (e), U5.1 (e), U6.1 (e), U7.1 (e)
unnamed: D1.1 (RK), D1.2 (GK), D1.3 (BK), D2.1 (RK), D2.2 (GK), D2.3 (BK), U1.2 (GRID13)
unnamed: D1.5 (GA), D3.5 (GA), D5.5 (GA), U1.10 (SEG2), U2.2 (d), U3.2 (d), U4.2 (d), U5.2 (d), U6.2 (d), U7.2 (d)
unnamed: D1.6 (RA), D3.6 (RA), D5.6 (RA), U1.11 (SEG3), U2.3 (c), U3.3 (c), U4.3 (c), U5.3 (c), U6.3 (c), U7.3 (c)
unnamed: D2.4 (BA), D4.4 (BA), D6.4 (BA), U1.12 (SEG4), U2.4 (g), U3.4 (g), U4.4 (g), U5.4 (g), U6.4 (g), U7.4 (g)
unnamed: D2.5 (GA), D4.5 (GA), D6.5 (GA), U1.13 (SEG5), U2.5 (dp), U3.5 (dp), U4.5 (dp), U5.5 (dp), U6.5 (dp), U7.5 (dp)
unnamed: D2.6 (RA), D4.6 (RA), D6.6 (RA), U1.14 (SEG6), U2.7 (a), U3.7 (a), U4.7 (a), U5.7 (a), U6.7 (a), U7.7 (a)
unnamed: D3.1 (RK), D3.2 (GK), D3.3 (BK), D4.1 (RK), D4.2 (GK), D4.3 (BK), U1.3 (GRID14)
unnamed: D5.1 (RK), D5.2 (GK), D5.3 (BK), D6.1 (RK), D6.2 (GK), D6.3 (BK), U1.4 (GRID15)
unnamed: J1.1, R2.2, U1.8 (SCLK)
unnamed: J1.2, R1.2, U1.7 (DIN)
unnamed: C1.2, C2.2, J1.3, U1.6 (VSS)
unnamed: C1.1, C2.1, J1.4, R1.1, R2.1, U1.17 (VDD)
unnamed: U1.18 (GRID1), U7.6 (b)
unnamed: U1.19 (GRID2), U7.9 (g)
unnamed: U1.20 (GRID3), U6.6 (b)
unnamed: U1.21 (GRID4), U6.9 (g)
unnamed: U1.22 (GRID5), U5.6 (b)
unnamed: U1.23 (GRID6), U5.9 (g)
unnamed: U1.24 (GRID7), U4.6 (b)
unnamed: U1.25 (GRID8), U4.9 (g)
unnamed: U1.26 (GRID9), U3.6 (b)
unnamed: U1.27 (GRID10), U3.9 (g)
unnamed: U1.28 (GRID11), U2.6 (b)
unnamed: U1.1 (GRID12), U2.9 (g)
unnamed: U1.15 (SEG7), U2.8 (b), U3.8 (b), U4.8 (b), U5.8 (b), U6.8 (b), U7.8 (b)
unnamed: U1.16 (SEG8), U2.10 (f), U3.10 (f), U4.10 (f), U5.10 (f), U6.10 (f), U7.10 (f)

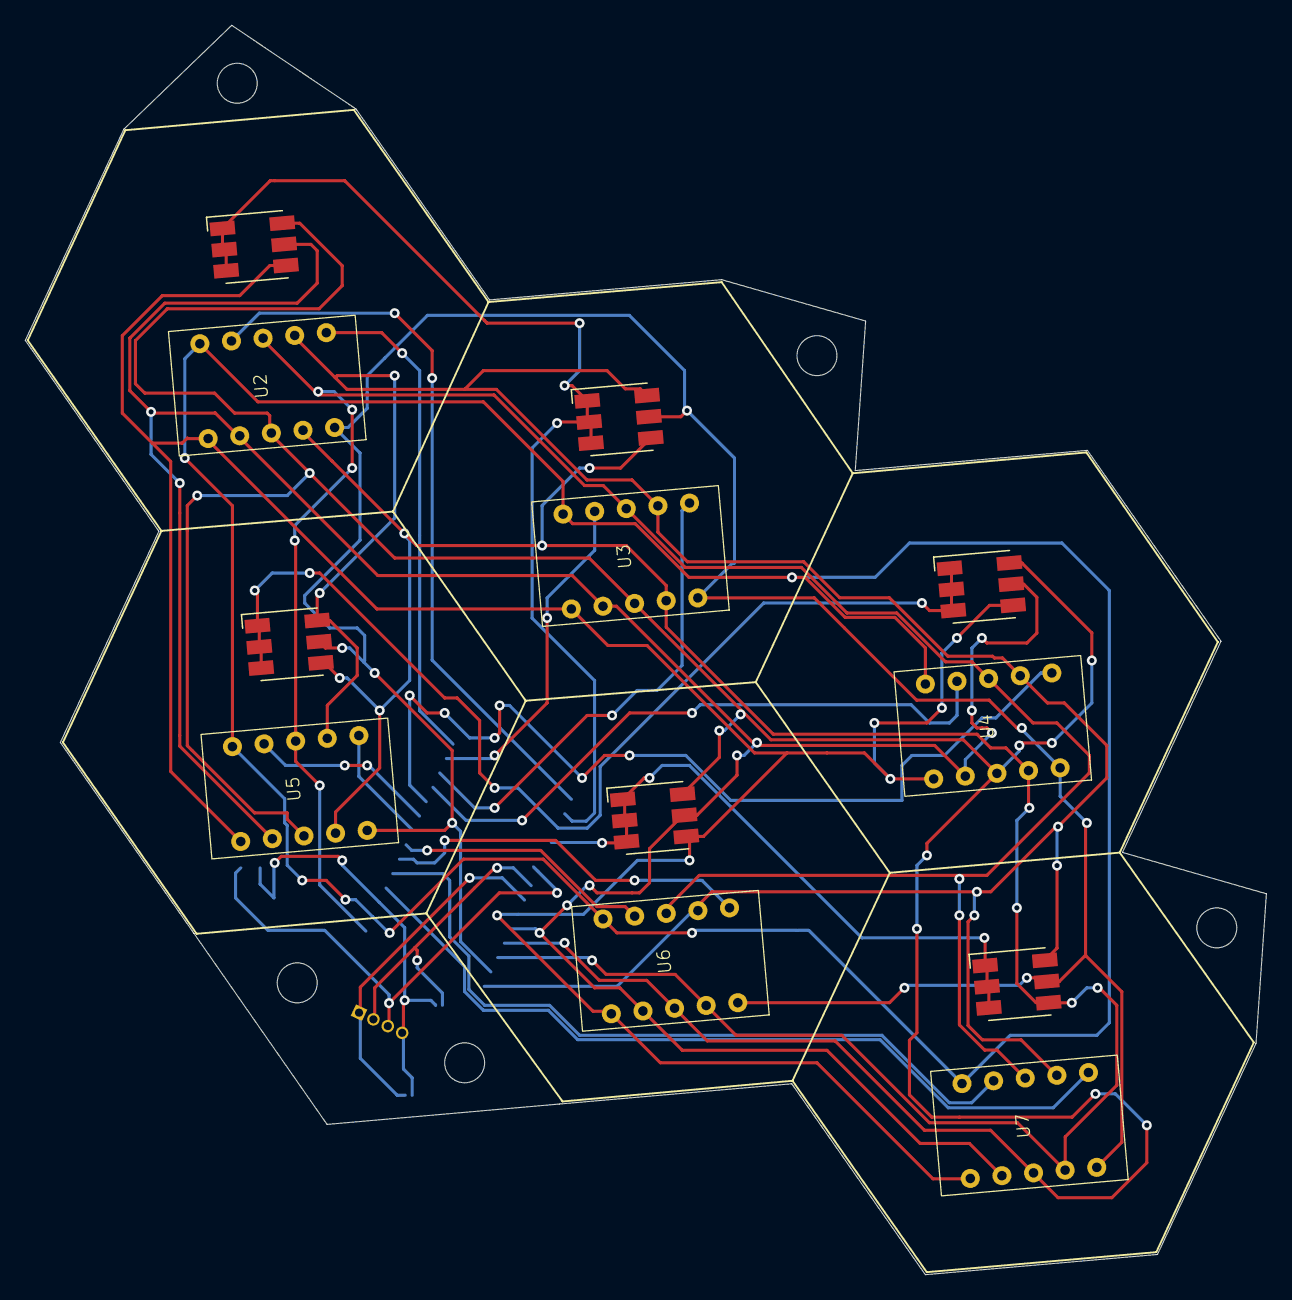
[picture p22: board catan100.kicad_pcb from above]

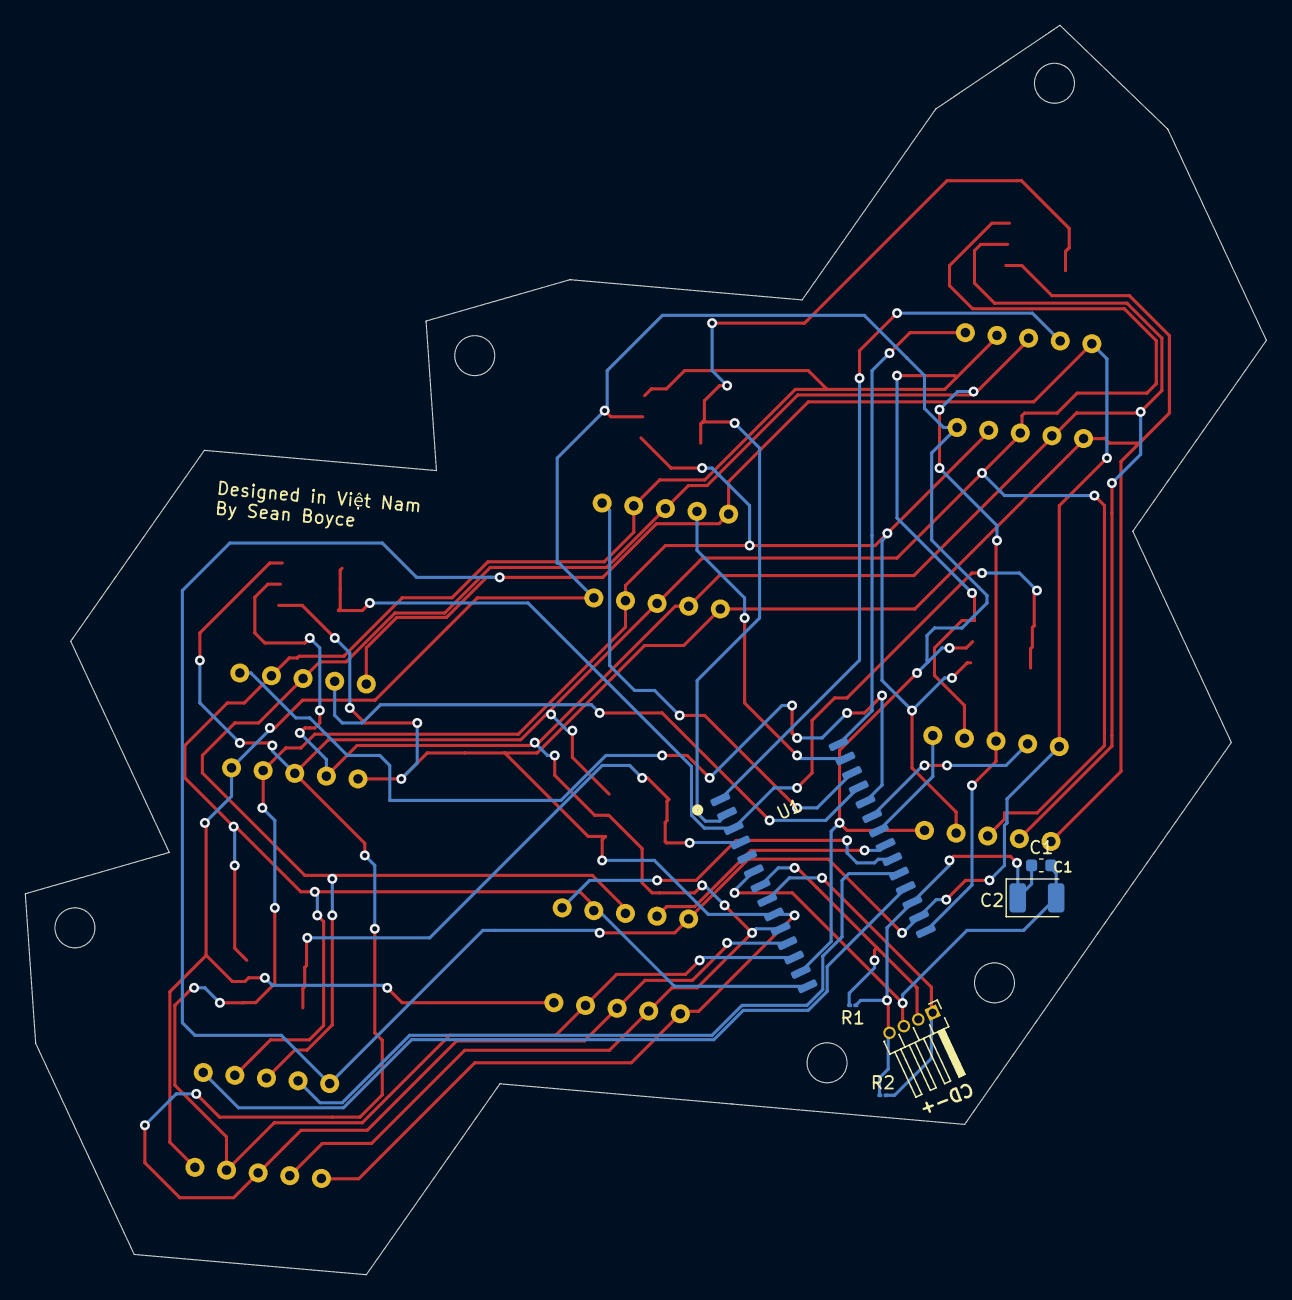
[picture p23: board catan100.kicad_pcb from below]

Board: 2 copper layers, 99.3 x 100.0 mm, 23 parts (6 on the bottom side), 27 nets.

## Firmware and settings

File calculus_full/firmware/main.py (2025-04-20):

import random
import tm1640
from machine import Pin, Timer

###
# Seeed XIAO RP2040 pins relative to RP2040 GPIO
# 
#         Arduino         RP2040 GPIO
#           Pin               Pin
#         ---------------------------
#         A0/D0                26
#         A1/D1                27
#         A2/D2                28
#         A3/D3                29
#         SDA/D4                6
#         SCL/D5                7
#         Tx/D6                 0
#         Rx/Csn/D7             1
#         SCK/D8                2
#         MISO/D9               4
#         MOSI/D10              3
###

##### General helper functions
#List flattener: Digits on LED displays are a list of lists. Convert to just a list.
def flatten_list(list_of_lists):
    return [item for row in list_of_lists for item in row]

#Fisher-Yates shuffle! An efficient randomization technique. Also a form of interpretive dance?
def shuffle(array):
    for i in range(len(array)-1, 0, -1):
        j = random.randrange(i+1)
        array[i], array[j] = array[j], array[i]
        
# Get the index of the tiles that produce a recource, based on a dice roll
def get_indices(lst, targets):
    return [index for index, element in enumerate(lst) if element in targets]

#Interrupt-driven dice roller with debounce. Rolls two dice twice, discards the first roll (probably uneccessary but I though I saw some RNG strangeness without it) 
#If the roll is 7, trigger the "robber"
def ISR_roll(pin):
  roll.irq(trigger=Pin.IRQ_RISING,handler=None)
  random.seed()
  global robber
  global indices
  global current_dice1
  global currentRoll
  current_dice1 =  random.randrange(1,7) 
  current_dice2 =  random.randrange(1,7)
  current_dice1 =  random.randrange(1,7) 
  current_dice2 =  random.randrange(1,7) 
  currentRoll = current_dice1 + current_dice2
  if currentRoll == 7:   
      robber = True
      indices = []
  else:
      indices = []
      robber = False
      currentRoll = num_order[(current_dice1 + current_dice2 - 2)]
      indices = [i for i, x in enumerate(values) if x == currentRoll]
  blinkState = False

# While the roll button is pressed down, blank the board. This is just cosmetic, to provide feedback to user action of pressing the "roll dice" button. 
def ISR_roll_start(pin):
    global current_dice1
    roll.irq(trigger=Pin.IRQ_FALLING,handler=None)
    current_dice1 = 0
    tm0.write([0, 0, 0, 0, 0, 0, 0, 0, 0, 0, 0, 0, 0, 0, 0, 0])
    tm1.write([0, 0, 0, 0, 0, 0, 0, 0, 0, 0, 0, 0, 0, 0, 0, 0])
    tm2.write([0, 0, 0, 0, 0, 0, 0, 0, 0, 0, 0, 0, 0, 0, 0, 0])
    tm3.write([0, 0, 0, 0, 0, 0, 0, 0, 0, 0, 0, 0, 0, 0, 0, 0])
    roll.irq(trigger=Pin.IRQ_RISING,handler=ISR_roll)
##### End General helper functions

##### Definitions  
#definitions for terrain. The bits in these integers represent which LEDs are on in the RGB LEDs that represent terrain types on the board.
hill = 2 #red
forest = 4 #green
field = 6 #yellow
mountain = 1 #blue
pasture = 7 #white
dead = 0 #none, for desert and 3:1 ports.

#we also define the numbers to display on the screen, this reflects how the segment displays are wired.
two = [int('01111011', 2),int('00000000', 2)]
three = [int('01111110', 2),int('00000000', 2)]
four = [int('11011100', 2),int('00000000', 2)]
five = [int('10111110', 2),int('00000000', 2)]
six = [int('10111111', 2),int('00000000', 2)]
eight = [int('11111111', 2),int('00000000', 2)]
nine = [int('11111110', 2),int('00000000', 2)]
ten = [int('11110111', 2),int('01000100', 2)]
eleven = [int('01010100', 2),int('01000100', 2)]
twelve = [int('01111011', 2),int('01000100', 2)]
desert = [int('00000000', 2),int('00000000', 2)]

#This list gives the display states the order we expect them to have. Rolls of 7 don't correspond to a tile.
num_order = [two,three,four,five,six,"robber",eight,nine,ten,eleven,twelve]

#The game has two dice, which sum to make the current roll. On startup, we init them to zero so the game knows it hasn't begun yet.
current_dice1 = 0
current_dice2 = 0
currentRoll = 0

#The state of the robber piece -- True means current player can move it. False means they cannot. We init it as False.
robber = False

#We will flash some segments when their value matches the dice roll. Init an empty list for the indices as well as a boolean to handle blinking.
indices = []
blinkState = True

#Choose 'roll dice!' pin.
roll = Pin(2, mode=Pin.IN, pull=Pin.PULL_UP)
#roll.irq(trigger=Pin.IRQ_RISING,handler=ISR_roll)
roll.irq(trigger=Pin.IRQ_FALLING,handler=ISR_roll_start)

##### End Definitions



##### Initialize a blank board (so we start from a known state on boot)
tm0 = tm1640.TM1640(clk=Pin(26), dio=Pin(27))
tm0.write([0, 0, 0, 0, 0, 0, 0, 0, 0, 0, 0, 0, 0, 0, 0, 0])
tm0.brightness(1)
tm1 = tm1640.TM1640(clk=Pin(28), dio=Pin(29))
tm1.write([0, 0, 0, 0, 0, 0, 0, 0, 0, 0, 0, 0, 0, 0, 0, 0])
tm1.brightness(1)
tm2 = tm1640.TM1640(clk=Pin(6), dio=Pin(7))
tm2.write([0, 0, 0, 0, 0, 0, 0, 0, 0, 0, 0, 0, 0, 0, 0, 0])
tm2.brightness(1)
tm3 = tm1640.TM1640(clk=Pin(0), dio=Pin(1))
tm3.write([0, 0, 0, 0, 0, 0, 0, 0, 0, 0, 0, 0, 0, 0, 0, 0])
tm3.brightness(1)
##### End blank board initilazation

##### Functions to initialize, assemble, and display the game data.

# Assemble game state into a list of bytes for the tm1640 to display
def assemble(segment_values,segment_terrain,segment_ports):
    # List of 16 bytes
    segment = segment_values # All 12 numerical display values
    segment_terrain.reverse() # LED positions are addressed backward relative to the numeric displays. I forget why. Probably the way I wired it.
    i = 0
    # Add Terrain RGB LED values
    while i<6:
        segment.append(segment_terrain[i] + 8*segment_terrain[i+1])
        i = i+2
        # Ports are a bit weird because we ran low on pins
        # D8 is RG (G16, pin 7,8) and B (G15 pin 8)    
    segment.append(segment_ports[1] + 8*segment_ports[2]) # Add trade ports 1,2
    # Aww no case/switch in micropython
    if segment_ports[0] == mountain:
        segment[14] = segment[14] + 128 # Set bit 8 for trade port 3, blue bit
    elif segment_ports[0] == pasture:
        segment[14] = segment[14] + 128 # Set bit 8 for trade port 3, blue bit
        segment[15] = segment[15] + 64 # Set bit 8 for trade port 3, green bit
        segment[15] = segment[15] + 128 # Set bit 8 for trade port 3, red bit
    elif segment_ports[0] == hill:
        segment[15] = segment[15] + 128 # Set bit 8 for trade port 3, red bit
    elif segment_ports[0] == forest:
        segment[15] = segment[15] + 64 # Set bit 7 for trade port 3, green bit
    elif segment_ports[0] == field:
        segment[15] = segment[15] + 64 # Set bit 8 for trade port 3, green bit
        segment[15] = segment[15] + 128 # Set bit 7 for trade port 3, red bit      
    elif segment_ports[0] == dead:
        pass
    return segment

# Take the lists that represent the game state, and assemble each into a list of bytes for each segment (4 total)
def init (values,terrain,ports):
    # Slice out the values for each segment
    segment1_values = flatten_list(values[:6])
    segment1_terrain = terrain[:6]
    segment1_ports = ports[:3]

    segment2_values = flatten_list(values[6:12])        
    segment2_terrain = terrain[6:12]
    segment2_ports = ports[3:6]

    segment3_values = flatten_list(values[12:18])
    segment3_terrain = terrain[12:18]
    segment3_ports = ports[-3:]

    # Center 'segment', just one tile
    segment4_values = flatten_list(values[-1:])
    segment4_terrain = terrain[-1:]
    # No ports in center tile

    # Assemble up 3 main segments, then the center tile
    segment1 = assemble(segment1_values,segment1_terrain,segment1_ports)
    segment2 = assemble(segment2_values,segment2_terrain,segment2_ports)
    segment3 = assemble(segment3_values,segment3_terrain,segment3_ports)
    segment4 = segment4_values
    segment4.append(segment4_terrain[0])
    return segment1,segment2,segment3,segment4


##### Function to display whatever you pass it on the board.         
def display(seg1, seg2, seg3,seg4):
    # first 12 grid positions on each segment are the 7-seg displays -- slice 6 from the array for each segment
    tm0.write(seg1)
    tm1.write(seg2)
    tm2.write(seg3)
    tm3.write(seg4)

##### End game data functions

##### Set up the game
# Randomize and set up the board -- define the terrain, numeric values, and ports. Then shuffle them around randomly. Also define a blank board state for convenience later.
terrain = [hill,hill,hill,field,field,field,field,pasture,pasture,pasture,pasture,mountain,mountain,mountain,forest,forest,forest,forest]
values = [two,three,three,four,four,five,five,six,six,eight,eight,nine,nine,ten,ten,eleven,eleven,twelve,desert]
ports = [dead,dead,dead,dead,hill,field,pasture,mountain,forest]
zeroValues = [desert]*20 # Blank board state.
# Randomize values and terrain
shuffle(terrain)
shuffle(values)
# Randomize trade ports
shuffle(ports)

# Insert the desert dead tile at the same index as the actual desert, but in the terrain list
desertIndex= values.index(desert)
terrain.insert(desertIndex, dead)
   
# Driver to assemble and display the game for the first time.
segment1, segment2, segment3, segment4 = init(values,terrain,ports)
display(segment1, segment2, segment3, segment4)


#Now, the main game loop
def main(x):
    global blinkState
    if current_dice1 > 0: #Will always be more than zero if the dice has been rolled at least once, e.g. the game has begun.
        if blinkState == True: # Display the board normally -- blink on whatever was previously off.
            segment1, segment2, segment3, segment4 = init(values,terrain,ports)
            display(segment1, segment2, segment3, segment4)
            roll.irq(trigger=Pin.IRQ_FALLING,handler=ISR_roll_start)
            blinkState = False
        else:
            if currentRoll == 7: # Oh my, a robber!
                segment1, segment2, segment3, segment4 = init(zeroValues,terrain,ports) # Turn off all numeric values on the board, to distract players while they are being robbed.
                display(segment1, segment2, segment3, segment4)
                blinkState = True
            else:
                rollIndex = [i for i, val in enumerate(values) if val == currentRoll]
                tempValues = values.copy()
                for i in rollIndex:
                    tempValues[i]=desert
                segment1, segment2, segment3, segment4 = init(tempValues,terrain,ports) # Turn off just the tiles that produce resources. 
                display(segment1, segment2, segment3, segment4)
                blinkState = True

        
# This handles blink rate
autoroller = Timer(mode=Timer.PERIODIC, period=250, callback=main)

# Do nothing by default. All the needed game logic is triggered by interrupts / timers.
while True:
    pass

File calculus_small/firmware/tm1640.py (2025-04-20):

"""
MicroPython TM1640 LED matrix display driver
https://github.com/mcauser/micropython-tm1640

MIT License
Copyright (c) 2017-2023 Mike Causer

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
from micropython import const
from machine import Pin
from time import sleep_us

__version__ = '1.0.1'

TM1640_CMD1 = const(64)  # 0x40 data command
TM1640_CMD2 = const(192) # 0xC0 address command
TM1640_CMD3 = const(128) # 0x80 display control command
TM1640_DSP_ON = const(8) # 0x08 display on
TM1640_DELAY = const(10) # 10us delay between clk/dio pulses

class TM1640(object):
    """Library for LED matrix display modules based on the TM1640 LED driver."""
    def __init__(self, clk, dio, brightness=7):
        self.clk = clk
        self.dio = dio

        if not 0 <= brightness <= 7:
            raise ValueError("Brightness out of range")
        self._brightness = brightness

        self.clk.init(Pin.OUT, value=0)
        self.dio.init(Pin.OUT, value=0)
        sleep_us(TM1640_DELAY)

        self._write_data_cmd()
        self._write_dsp_ctrl()

    def _start(self):
        self.dio(0)
        sleep_us(TM1640_DELAY)
        self.clk(0)
        sleep_us(TM1640_DELAY)

    def _stop(self):
        self.dio(0)
        sleep_us(TM1640_DELAY)
        self.clk(1)
        sleep_us(TM1640_DELAY)
        self.dio(1)

    def _write_data_cmd(self):
        # automatic address increment, normal mode
        self._start()
        self._write_byte(TM1640_CMD1)
        self._stop()

    def _write_dsp_ctrl(self):
        # display on, set brightness
        self._start()
        self._write_byte(TM1640_CMD3 | TM1640_DSP_ON | self._brightness)
        self._stop()

    def _write_byte(self, b):
        for i in range(8):
            self.dio((b >> i) & 1)
            sleep_us(TM1640_DELAY)
            self.clk(1)
            sleep_us(TM1640_DELAY)
            self.clk(0)
            sleep_us(TM1640_DELAY)

    def brightness(self, val=None):
        """Set the display brightness 0-7."""
        # brightness 0 = 1/16th pulse width
        # brightness 7 = 14/16th pulse width
        if val is None:
            return self._brightness
        if not 0 <= val <= 7:
            raise ValueError("Brightness out of range")

        self._brightness = val
        self._write_data_cmd()
        self._write_dsp_ctrl()

    def write(self, rows, pos=0):
        if not 0 <= pos <= 7:
            raise ValueError("Position out of range")

        self._write_data_cmd()
        self._start()

        self._write_byte(TM1640_CMD2 | pos)
        for row in rows:
            self._write_byte(row)

        self._stop()
        self._write_dsp_ctrl()

    def write_int(self, int, pos=0, len=8):
        self.write(int.to_bytes(len, 'big'), pos)

    def write_hmsb(self, buf, pos=0):
        self._write_data_cmd()
        self._start()

        self._write_byte(TM1640_CMD2 | pos)
        for i in range(7-pos, -1, -1):
            self._write_byte(buf[i])

        self._stop()
        self._write_dsp_ctrl()

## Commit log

2025-03-08 Add smaller, cheaper version of Calculus
    [calculus100.kicad_pcb, calculus100.kicad_sch]
2025-03-08 Add image of completed board
2025-03-17 Create BOM
2025-03-17 Update BOM
2025-04-14 Add files via upload
    Add photos of new board
2025-04-14 Update README.md
    Add some notes on full-size board
2025-04-20 Add files via upload
    Add photography of fully working board
2025-04-20 Add files via upload
    Upload files for production. Note these are metric.
    [catan100-B_Cu.gbr, catan100-B_Mask.gbr, catan100-B_Paste.gbr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]
2025-04-20 Delete calculus_full/production files directory
    wrong directory name
    [catan100-B_Cu.gbr, catan100-B_Mask.gbr, catan100-B_Paste.gbr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]
2025-04-20 Add files via upload
    add center tile kicad files
    [Catancenter.kicad_sch]
2025-04-20 Add files via upload
    add main segment kicad files
    [catan100.kicad_pcb, catan100.kicad_sch]
2025-04-20 Update and rename BOM to BOM.md
    update BOM
2025-04-30 Add files via upload
    Add 0603 (1608 metric) version. This replaces the tiny resistors with larger, easier to solder ones. No other changes besides resistor package size.
2025-06-04 Add files via upload
    Start adding print materials
2025-06-04 Add files via upload
    Add in only sort of bad print materials
2025-06-07 Delete print materials/reference_cards_print_2x.pdf
    Need to fix some text
2026-03-14 Create README.MD
    Notes on print materials
2026-03-15 Update README.md
    Add notes on USB power bank automatic power off prevention.
2026-03-15 Update README.md
    Update to include improvements to print materials.
2026-03-15 Update README.md
    Add notes on structural support for the finished boards.
